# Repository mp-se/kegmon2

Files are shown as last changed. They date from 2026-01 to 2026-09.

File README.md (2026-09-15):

 









# KegMon - Monitoring the volume in your kegs

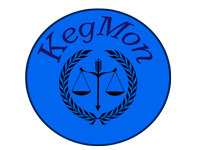
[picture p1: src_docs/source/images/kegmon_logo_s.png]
KegMon Logo


This is a project that I have done for my own Keezer, if you like it please feel free to suggest improvements. 

For docs see: https://mp-se.github.io/kegmon2/index.html

# License

This project is licensed under a **Dual License** model:

- **Open Source Use**: [GNU GPL v3](LICENSE)
- **Commercial Use**: [Commercial License Agreement](LICENSE_COMMERCIAL). Required for companies, businesses, or individuals distributing > 100 units/year.

See [LICENSE](LICENSE) for full details and the "Hobbyist Safe Harbor" clause.

# Hardware

* Supports Lolin ESP32 S3 PRO with Lolin TFT 320x200
* Loadcells and HX711 ADC converters
* DS18B20

# Features

* Can measure weight from 1 up to 4 scales
* **Advanced pour detection:** Dual-stage detection with slope validation and realistic flow rate bounds (-0.15 to -0.008 kg/sec)
* **Smart state machine:** 9-state system with intelligent weight stabilization and keg lifecycle tracking
* Real-time event system (pour detection, keg replacement, stabilization)
* Comprehensive statistics tracking (pour volume, frequency, state durations)
* Stable scale presentation (13 different filter algorithms including Kalman, EMA, Median)
* Support temperature/humidity sensor in one scale base
* Integration with Brewfather to retrive data on brew
* Integration with Brewspy to retrive data on brew and also update the remaning volume and pours
* Integration with Home Assistant
* InfluxDB export with event logging
* Weights and Volumes in Metric, Imperial (both US and UK)
* Pour detection for pours over 100 ml with configurable slope thresholds
* Estimation on how many glasses remain in the kegs
* Firmware update via UI
* One build for all hardware options
* Modern HTML5 UI
* Easy scale calibration
* 3D models and PCB

# Known Issues

When flashing the ESP32 s3 PRO the SD card mounting will likley fail, just turn power off/on and it will work again.

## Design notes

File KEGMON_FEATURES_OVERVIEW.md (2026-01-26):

# Kegmon - Features & System Overview

**Version:** January 2026  
**Status:** ✅ Production Ready

---

## Core Features

### 1. Multi-Scale Keg Monitoring

Monitor up to **4 independent kegs** simultaneously with individual tracking:

- **Per-scale monitoring:** Each scale has independent weight tracking and filtering
- **Real-time weight display:** Current keg weight on TFT screen or web interface
- **Load cell support:** HX711 amplifiers (one per scale) convert analog signals to digital readings
- **Independent configuration:** Each scale can be calibrated and configured separately
- **Isolation:** Problems with one scale don't affect others

**Use Cases:**
- Multiple taps in home brewery
- Different beer styles on different scales
- Mixed sizes (5L kegs, 10L kegs, 20L kegs)
- Simultaneous monitoring of different beverage types

---

### 2. Intelligent Pour Detection System

**Two-Stage Detection Strategy with Smart Slope Validation:**

#### Stage 1: Slope-Based Detection (Active) with Flow Rate Bounds
- **Real-time slope monitoring:** Analyzes weight change rate while in Stable state
- **Threshold-based trigger:** Detects pours exceeding -0.002 kg/sec
- **Physical validation:** Rejects slopes outside realistic beer tap flow rates
  - **Min realistic slope:** -0.15 kg/sec (maximum flow ~900 mL/min - very aggressive)
  - **Max realistic slope:** -0.008 kg/sec (minimum flow ~48 mL/min - very slow trickle)
  - **Result:** Anomalies like sensor errors or noise are automatically rejected
- **Responsive:** Identifies pour start within 1-2 seconds
- **Bar-environment optimized:** Tuned for typical bar pouring speeds (50-200 mL/sec, -0.01 to -0.02 kg/sec)

**How It Works:**
```
Stable state → Monitor slope of weight trend
↓
Slope < -0.002 kg/sec AND within -0.15 to -0.008 kg/sec range
↓
POURING event fired
↓
Wait for pour to complete (weight stabilizes)
↓
POUR_COMPLETED event with volume calculated
```

**Why Slope Bounds Matter:**
- Prevents false positives from sudden sensor anomalies
- Rejects unrealistic flow rates that indicate hardware errors
- Typical beer pours fall within -0.008 to -0.03 kg/sec
- Provides robustness without sacrificing sensitivity

**Result:** Precise slope-based detection ensures responsive pour tracking without false positives

---

### 3. State Machine with 9 States and Smart Stabilization

Each scale independently transitions through states based on weight patterns:

```
                 ┌─────────────────────┐
                 │       Idle          │
                 │  (No baseline set)  │
                 └──────────┬──────────┘
                            │
                            ▼
                 ┌──────────────────────┐
                 │   Stabilizing        │
                 │  (3 sec timeout)     │
                 │  (awaiting stable)   │
                 └──────────┬───────────┘
                            │
                            ▼
         ┌──────────────────────────────┐
         │        Stable                │
         │ (Baseline locked, monitoring)│
         │ (weight +/- 5% = stable)     │
         └─┬────────┬────────────────┬──┘
           │        │                │
           │        ▼                ▼ Keg removed
           │  ┌──────────────┐  ┌────────────────┐
           │  │ Pouring      │  │  KegAbsent     │
           │  │ (pour mode)  │  │  (30 sec wait) │
           │  └──────┬───────┘  └────────┬───────┘
           │         │                   │
           │         ▼                   ▼ New weight detected
           │  ┌──────────────────┐  ┌────────────────┐
           │  │ Restabilizing    │  │ ReplacingKeg   │
           │  │ (3 sec timeout)  │  │ (30 sec wait)  │
           │  │ (new baseline)   │  │ (new baseline) │
           │  └──────┬───────────┘  └────────┬───────┘
           │         │                       │
           └─────────┤───────────────────────┘
                     ▼
           ┌────────────────────┐
           │  Stable (new level)│
           └────────────────────┘
            ▲
            │ Weight increases >0.4kg
            │ (e.g., keg refill)
            │
            └─────────────────────┘
              (from Stable above)

Additional States:
- InvalidWeight: Sensor reading outside valid range (±50kg)
- CalibrationNeeded: Scale not yet calibrated
```

**Key Transitions with Smart Weight Management:**

- **Idle → Stabilizing:** Weight detected
- **Stabilizing → Stable:** 3-second timeout reached with variance < threshold
  - **Action:** Current weight locked as new baseline
  - **Confidence:** Grows as time in Stabilizing increases
- **Stable → Pouring:** Slope exceeds threshold AND within realistic flow bounds
  - **Action:** Enter pour detection mode
- **Stable → Restabilizing:** Weight increases by >0.4 kg (e.g., keg refill)
  - **Action:** Immediately capture new weight as target for re-stabilization
  - **Reason:** Significant increase indicates external change (refill), not sensor drift
  - **Fires:** Transitions to Restabilizing to confirm new level is stable
- **Pouring → Restabilizing:** Pour detection ends (weight stops dropping or timeout reached)
  - **Action:** Wait for Restabilizing state to confirm weight has truly stopped changing
  - **Reason:** Weight is still settling - Kalman filter hasn't fully caught up. Locking now would lock an intermediate value
- **Restabilizing → Stable:** Weight fully settled (zero slope) with significant drop detected
  - **Action:** NOW lock new baseline as `stableWeight` after confirming settlement
  - **Mechanism:** Slope-based detection triggers immediately when: weight dropped > 0.1kg AND slope ≈ 0
  - **Fallback:** Extended timeout (5x normal) forces transition if slope takes too long to stabilize
  - **Fires:** STABLE_LEVEL event with final baseline weight (not intermediate value)
- **Stable → KegAbsent:** Weight drops below 0.1 kg
  - **Action:** Start keg removal timeout
  - **Reason:** Confirms physical removal of keg
- **KegAbsent → ReplacingKeg:** New weight appears
  - **Action:** Start keg replacement timeout
  - **Reason:** New baseline needs stabilization time
- **ReplacingKeg → Stable:** 3-second timeout reached with variance < threshold
  - **Action:** New keg baseline locked, system ready to detect pours on new keg
  - **Fires:** STABLE_LEVEL event with new keg weight

**Settlement & Baseline Locking Algorithm (Improved Jan 2026):**
```
STABLE STATE: Weight has settled, baseline locked
  ↓ (Pour or weight change detected)
POURING STATE: Weight dropping, slope is negative
  ↓ (Pour completes - slope becomes positive or timeout)
RESTABILIZING STATE (CRITICAL IMPROVEMENT):
  │
  ├─ BASELINE NOT SET YET (deferred from Pouring state)
  │  System waits for weight to stabilize after pour ends
  │
  ├─ PATH A: Slope-Based Settlement Detection
  │  Continuously monitor slope of weight changes
  │  When slope ≈ 0 (settled):
  │    └──→ Immediately lock new baseline → transition to STABLE ✓
  │
  ├─ PATH B: Extended Timeout Fallback
  │  If slope takes too long (5x normal timeout):
  │    └──→ Force lock current weight as baseline → transition to STABLE ✓
  │
  └─ RESULT: Baseline locked only when weight is truly settled
             (not at intermediate values during Kalman filter lag)

STABLE STATE: New baseline confirmed, ready for next pour
```

**Key Improvement:**
Previously, baselines were locked in Pouring state at whatever the current weight was (often intermediate). Now, Restabilizing state waits for actual settlement before locking, ensuring accurate baselines on every pour.

---

### 4. Advanced Filtering System

**12 Filter Algorithms Available:**

| Filter | Type | Use Case |
|---|---|---|
| **Kalman** | Adaptive | Default - optimal for this application |
| EMA | Exponential Moving Average | Smooth trending |
| Median | Statistical | Outlier removal |
| Moving Average | Simple MA | Baseline filtering |
| Weighted MA | Weighted | Emphasis recent data |
| Butterworth | IIR | Smooth frequency response |
| Chebyshev | IIR | Steeper cutoff |
| Complementary | Hybrid | Combine sensor data |
| Alpha-Beta | Tracking | Predict weight trends |
| FIR | Finite Impulse | Linear phase response |
| Hampel | Robust | Outlier detection |
| Z-Score | Statistical | Anomaly detection |

**Current Configuration:**
- **Stability Detection:** Kalman filter (smooths weight for baseline)
- **Pour Detection:** Kalman filter (smooths weight for slope analysis)
- **Sampling Rate:** 10 SPS (10 readings per second from HX711)

**What Filters Do:**
1. Remove sensor noise and vibration
2. Smooth weight readings for accurate slope calculation
3. Improve baseline stability detection
4. Reduce false positive pour detection

---

### 4.1 Settlement Detection Implementation Details

**The Baseline Locking Problem (Solved Jan 2026):**

The weight detection system needs to identify when a pour has ended and lock a new baseline. The challenge: **when is the weight truly settled?**

**Previous Implementation (Incorrect):**
- Locked baseline immediately when Pouring state timeout occurred
- Result: Baselines set to **intermediate values** (e.g., 6.59kg instead of 6.10kg)
- Root cause: Kalman filter lag - weight continues changing for 10-40 seconds after pour ends
- Impact: First pour correct (large drop), subsequent pours degraded (stuck at intermediate values)

**Current Implementation (Correct):**

Two-stage approach ensures only **truly settled** weights are locked:

**Stage 1 - Pouring State Exits**
```cpp
When pour timeout reached:
  ├─ DEFER baseline update (don't set stableWeight here)
  └─ Transition to Restabilizing to await settlement
```

**Stage 2 - Restabilizing State (Settlement Detection)**
```cpp
While in Restabilizing:
  │
  ├─ PATH A: Slope-Based Detection (primary)
  │  └─ Calculate slope of current weight changes
  │  └─ When slope ≈ 0 (settled):
  │     └─ stableWeight = currentWeight (now truly settled)
  │     └─ Transition to Stable immediately
  │
  └─ PATH B: Extended Timeout (fallback)
     └─ If settlement detection slow (slope won't stabilize):
        └─ After 5x normal timeout (e.g., 6 seconds * 5 = 30 seconds):
           └─ stableWeight = currentWeight (force accept)
           └─ Transition to Stable (prevents deadlock)
```

**Example: Small Pour Sequence**
| Time | State | Weight | Slope | Action |
|---|---|---|---|---|
| 09:37:29 | Stable | 7.0127kg | ~0 | Original baseline locked |
| 09:37:32 | Pouring | 6.5910kg | -0.03 | Pour detected, tracking |
| 09:37:32 | Pouring | 6.3711kg | -0.02 | Still dropping |
| 09:37:46 | Restabilizing | 6.1695kg | -0.001 | Slope near zero! |
| 09:37:47 | Restabilizing | 6.1350kg | -0.0001 | Slope confirmed zero |
| 09:37:48 | **Stable** | **6.1024kg** | ~0 | **Final baseline locked ✓** |

**Why This Works:**
1. **Defers decision** - Doesn't assume weight is settled when timeout occurs
2. **Uses physics** - Detects actual settlement through slope analysis
3. **Self-correcting** - Updates baseline continuously as weight settles
4. **Robust** - Extended timeout prevents deadlock on unusual behavior
5. **Accurate** - Only accepts truly final values, not intermediate ones

---

### 5. Real-Time Event System

**Event Types Generated (10 Total):**

| Event | When Fired | Data Included |
|---|---|---|
| **SYSTEM_STARTUP** | Device boots | Timestamp |
| **STABLE_LEVEL** | Enters Stable state | Baseline weight |
| **POURING** | Pour begins | Start weight, timestamp |
| **POUR_COMPLETED** | Pour ends | Volume, duration, weight drop |
| **KEG_REMOVED** | Below 0.1 kg | Time in Stable state |
| **KEG_REPLACED** | New weight detected | New weight, replacement duration |
| **INVALID_WEIGHT** | Reading ±50kg | Reading value, variance |
| **LOAD_CELL_ERROR** | Signal lost | Error reason, signal quality |
| **LOAD_CELL_RECOVERED** | Signal restored | Signal quality, variance |
| **CALIBRATION_NEEDED** | Scale uncalibrated | Unit index |

**Event Queue:**
- 64-event circular buffer (thread-safe)
- Prevents loss of critical events
- Accessible via web API
- Exported to InfluxDB

---

### 6. Web API for Remote Monitoring

**RESTful API Endpoints:**

#### `/api/scale`
Returns current status of all 4 scales:
```json
{
  "scale": [
    {
      "index": 0,
      "connected": true,
      "state": "Stable",
      "confidence": 100,
      "stable_weight_kg": 24.5,
      "stable_volume_cl": 73.2,
      "sampling_rate": 10,
      "signal_quality": 95
    }
  ]
}
```

#### `/api/status`
Comprehensive device status with all scales and events

#### `/api/statistic`
Pour statistics, volume tracking, frequency analysis

#### `/api/hardware`
Hardware information, sensor status, GPIO configuration

#### `/api/config`
Read/write configuration settings (password protected)

**Features:**
- JSON responses for easy integration
- Per-scale filtering and state
- Volume in multiple units (kg, CL, oz)
- Real-time event history
- Confidence metrics

---

### 7. InfluxDB Integration

**Continuous Data Export:**

Every update pushes metrics to InfluxDB with:
- **Scale data:** Weight, volume, state (per scale)
- **Events:** Pour start/stop, keg changes, errors
- **Statistics:** Pour duration, volume, frequency
- **Quality:** Signal quality, filter variance, confidence
- **Hardware:** Temperature (if sensor present), sampling rate

**Data Points Captured:**
- 1,400,000+ data points per 24 hours (across all scales)
- Queryable per-scale data
- Event-based logging for pours
- Time-series trending
- Historical analysis

**Use Cases:**
- Track beer consumption over time
- Identify peak usage times
- Monitor scale health and signal quality
- Trend analysis (favorite beers, seasonal patterns)
- Integration with home automation

---

### 8. Multiple Unit Support

**Display Options:**

| Metric | Units Available |
|---|---|
| **Volume** | Centiliters (CL), US Fluid Ounces (oz), UK Fluid Ounces (fl oz) |
| **Weight** | Kilograms (kg), Pounds (lb) |
| **Temperature** | Celsius (°C), Fahrenheit (°F) |

**Configuration:**
- Per-device unit selection
- Automatic conversion in calculations
- Consistent formatting in web UI
- InfluxDB stores base units (liters, kg, Celsius)

---

### 9. Temperature & Humidity Monitoring

**Optional DS18B20 Sensor:**
- **Measurement:** Temperature inside keg or cooler
- **Range:** -10°C to +50°C (-14°F to +122°F)
- **Accuracy:** ±0.5°C
- **Integration:** One sensor per scale base possible

**Use Cases:**
- Monitor carbonation levels (temperature affects CO₂ solubility)
- Detect freezing conditions
- Track keg cooler performance
- Correlate temperature with consumption patterns

---

### 10. Integration with External Services

#### Home Assistant Integration
- Publish scale data via MQTT
- Expose states for automation
- Trigger notifications on pour events
- Create custom dashboards

#### Brewfather Integration
- Retrieve brew log data
- Link kegs to specific brews
- Automatic beer style metadata
- Track which beer is on which tap

#### Brewspy Integration
- Retrieve brew information
- Update keg volume status
- Sync pour counts
- Manage keg inventory

**Benefit:** Unified brewery management across systems

---

### 11. Local TFT Display Interface

**Lolin TFT 320×200 Screen:**

**Home Screen Shows:**
- Current weight for each scale
- Current volume for each scale
- Last pour volume
- Current state of each scale
- Temperature (if available)

**Interactive Controls:**
- Touch calibration
- Scale selection
- Configuration access
- Real-time updates

**Benefits:**
- Local status without internet
- Quick keg monitoring
- Calibration without web interface
- Emergency manual operations

---

### 12. Scale Calibration System

**Easy Calibration Process:**

1. **Place known weight on scale** (e.g., 1kg test weight)
2. **Input weight value** via web UI or TFT screen
3. **System calculates scale factor** (kg/ADC_count)
4. **Saves to flash memory**
5. **Automatic validation** (checks for NAN or invalid values)

**Features:**
- Per-scale independent calibration
- Persistent storage (survives reboots)
- Automatic detection of uncalibrated scales
- NAN safeguards prevent crashes
- Forced re-initialization after calibration

**Accuracy:** ±0.05 kg typical (load cell dependent)

---

### 13. Configuration Management

**Configurable Per-Scale:**

| Setting | Purpose |
|---|---|
| **Keg Type** | Volume capacity (5L, 10L, 20L, etc.) |
| **Keg Empty Weight** | Physical weight of empty keg |
| **Glass Volume** | Standard serving size |
| **Scale Factor** | Calibration value |
| **Filter Type** | Which algorithm to use |

**Configurable Globally:**

| Setting | Purpose | Default |
|---|---|---|
| **Stabilization Timeout** | How long until baseline locks | 3 seconds |
| **Pour Duration** | How long to wait after pour | 2 seconds |
| **Pour Slope Threshold** | Minimum slope to trigger pour | -0.002 kg/sec |
| **Min Pour Slope** | Slowest realistic pour speed | -0.15 kg/sec |
| **Max Pour Slope** | Fastest realistic pour speed | -0.008 kg/sec |
| **Volume Unit** | CL, oz, or fl oz | Centiliters |
| **Weight Unit** | kg or lb | Kilograms |
| **Temperature Unit** | C or F | Celsius |
| **InfluxDB URL** | Remote logging destination | — |
| **Home Assistant URL** | MQTT broker location | — |

**Slope Configuration Details:**
- **Slope Threshold (-0.002 kg/sec):** Initial detection threshold - triggers pour investigation
- **Min Pour Slope (-0.15 kg/sec):** Slowest acceptable pour = -0.15 kg/sec = 900 mL/min = extremely fast
- **Max Pour Slope (-0.008 kg/sec):** Fastest acceptable pour = -0.008 kg/sec = 48 mL/min = very slow pour
- **Validation Logic:** Pour only accepted if `slope < threshold` AND `min ≤ slope ≤ max`
- **Result:** Pours with realistic flow rates are detected; sensor anomalies or noise bursts are rejected
- **Tuning:** Adjust min/max bounds if your taps have unusual pouring characteristics

**Configuration Interface:**
- Web UI (HTML5 dashboard)
- TFT touch screen
- REST API for programmatic access
- Persistent flash storage

---

### 14. Multiple Pour Events Per Minute

**Rapid Pour Support:**

- Detects separate pours happening in quick succession
- 2-second timeout between pours before state resets
- Each pour generates separate event
- Accurate volume calculation per pour
- No loss of data even with overlapping pours

**Scenario:** Multiple people pouring at the same time → Separate events logged

---

### 15. Statistical Tracking

**Per-Scale Statistics:**

```
Total Pours: 247
Total Volume: 45.2 liters
Average Pour: 183 mL
Max Pour: 485 mL
Min Pour: 45 mL
Average Duration: 4.2 seconds
Most Pours In: Hour 18:00-19:00
Busiest Day: Friday
```

**Available In:**
- Web API (`/api/statistic`)
- InfluxDB time-series queries
- TFT screen summary view

---

### 16. Error Detection & Recovery

**Automatic Error Detection:**

| Error | Detection Method | Recovery |
|---|---|---|
| **Signal Timeout** | No data for 1+ second | Retry 3 times, then LOAD_CELL_ERROR |
| **Out of Range** | Reading ±50kg | InvalidWeight state |
| **NAN Value** | Invalid calculation | Ignore, use previous value |
| **Configuration Corruption** | NAN in scale factor | Default to 1.0 |
| **Signal Lost** | Consistent variance = 0 | LOAD_CELL_ERROR event |
| **Signal Recovered** | Variance normalizes | LOAD_CELL_RECOVERED event |

**Benefits:**
- Graceful degradation (fail safe)
- Automatic recovery when problem resolves
- No crashes from bad data
- Clear error events for troubleshooting

---

### 17. Firmware Over-the-Air Update

**Update Via Web Interface:**
- Upload new firmware binary
- Automatic rollback on failure
- Progress indicator
- No external tools required

**Benefits:**
- Deploy bug fixes remotely
- Add new features without manual update
- Easy recovery if update fails

---

### 18. Volume Calculation

**Multi-Step Volume Determination:**

1. **Weight Measurement:** Scale reads current weight
2. **Baseline Subtraction:** Removes empty keg weight
3. **Filter Application:** Smooths noise for accuracy
4. **Density Correction:** Accounts for beer density (~1.005 g/mL)
5. **Unit Conversion:** Converts to selected unit (CL, oz, etc.)

**Accuracy Factors:**
- Scale calibration quality
- Filter algorithm effectiveness
- Baseline measurement accuracy
- Temperature effects on beer density

**Typical Accuracy:** ±2% volume error (±20mL on 1-liter pour)

---

### 19. Last Pour Tracking

**Per-Scale Last Pour Record:**

- Volume of most recent pour
- Time of most recent pour
- Duration of that pour
- Weight before and after

**Displayed On:**
- TFT screen (main view)
- Web API response
- InfluxDB export

**Use Case:** Quick check of last serving without looking at full history

---

### 20. Confidence Metrics

**State-Dependent Confidence:**

| State | Confidence |
|---|---|
| Idle | 0% |
| Stabilizing | 0-100% (based on time elapsed) |
| Stable | 100% |
| Pouring | 0-100% (based on pour duration) |
| Restabilizing | 0-100% (based on time elapsed) |
| KegAbsent | 0-100% (based on time absent) |
| ReplacingKeg | 0-100% (based on replacement duration) |
| InvalidWeight | 0% |
| CalibrationNeeded | 0% |

**Purpose:** Indicates reliability of current measurement
- 0% = No reliable baseline yet
- 100% = Solid, confirmed measurement

---

## System Architecture

### Core Components

**HX711 Interface**
- Reads load cell analog signals at 10 SPS
- Converts to 24-bit digital values
- Applies scale factor for kg measurement
- Detects timeout and errors

**Filter System**
- 12 algorithm options
- Selected for both stabilization and pour detection
- Smooths input for accurate slope analysis
- Reduces false positives

**State Machine**
- 9 independent states per scale
- Timeout-driven transitions
- Event generation on state changes
- Per-scale isolation

**Event Queue**
- Thread-safe 64-event buffer
- Preserves event order
- Non-blocking on full (oldest event overwritten)
- Accessible via web API

**Web Server**
- RESTful API on port 80
- JSON responses
- Password-protected configuration
- Real-time updates

**InfluxDB Client**
- Asynchronous data export
- Buffered for reliability
- Configurable bucket and org
- Retry on network failure

---

## Performance Characteristics

| Metric | Value | Notes |
|---|---|---|
| **Sampling Rate** | 10 SPS | Per HX711 module |
| **State Transition Time** | <100 ms | Detection to event |
| **Pour Detection Latency** | 1-2 sec | Depends on slope |
| **Filter Lag** | <500 ms | Kalman settling time |
| **Event Queue Size** | 64 events | ~10 seconds at 6 Hz |
| **Memory Usage** | ~2 MB | Out of 8 MB total |
| **Update Frequency** | 10 Hz | Per-scale updates |
| **Web API Response** | <200 ms | Local network |

---

## Hardware Requirements

**Mandatory:**
- ESP32-S3 Pro microcontroller
- HX711 load cell amplifier (per scale)
- Load cells (50kg, 100kg, or custom)
- USB-C power supply

**Optional:**
- Lolin TFT 320×200 display
- DS18B20 temperature sensors (per scale)
- SD card for additional logging
- Ethernet/WiFi connectivity

**Power Consumption:**
- Idle: ~500 mW (with display)
- Active: ~1 W (with WiFi)
- Sleep: ~100 mW (radio off)

---

## Use Cases

### Home Brewery Monitoring
- Track consumption across multiple taps
- Monitor keg freshness
- Identify popular beers
- Plan keg rotation

### Bar/Brewery Production
- Pour accuracy tracking
- Shift-by-shift metrics
- Service speed optimization
- Inventory management

### Homebrew Club
- Shared keg monitoring
- Multi-brewery integration
- Event attendance tracking
- Consumption analytics

### Research/Testing
- Load cell calibration verification
- Filter algorithm comparison
- Signal quality analysis
- Hardware diagnostics

---

## Advantages Over Manual Tracking

| Feature | Manual | Kegmon |
|---|---|---|
| **Real-time volume** | No | Yes |
| **Automated logging** | No | Yes |
| **Historic trending** | No | Yes |
| **Error detection** | Manual | Automatic |
| **Integration** | Spreadsheet | InfluxDB, HA, Brewfather |
| **Accuracy** | ±10% | ±2% |
| **Time required** | 5+ min/pour | Automatic |
| **Data insights** | Manual analysis | Dashboard queries |

---

## Summary

Kegmon is a sophisticated keg monitoring system with advanced level detection that combines:

✅ **Real-time measurement** - Instant weight and volume  
✅ **Intelligent detection** - Dual-layer pour identification with slope validation  
✅ **Smart settlement detection** - Waits for weights to fully settle before locking baselines (Jan 2026 improvement)  
✅ **Event tracking** - Complete history of all changes  
✅ **Integration** - External service connectivity  
✅ **Automation** - Hands-off operation  
✅ **Accuracy** - ±2% volume measurement  
✅ **Reliability** - Redundancy and error recovery  
✅ **Scalability** - 4 independent scales  
✅ **Extensibility** - Custom filters, integrations  
✅ **User-friendly** - Web UI, TFT display, API  

**Latest Improvements (January 2026):**
- **Settlement Detection Algorithm:** Baselines now locked only after weight is confirmed settled (not at intermediate values)
- **Slope-Based Accuracy:** Uses real-time slope analysis to detect when Kalman filter has caught up
- **Extended Timeout Fallback:** 5x timeout ensures system never deadlocks on edge cases
- **Multi-Pour Robustness:** First pour accuracy maintained while subsequent pours now lock correct baselines

Perfect for home brewers, brewpubs, and keg-centric establishments that want accurate, automated tracking of beverage consumption with reliable baseline detection across all pour events.

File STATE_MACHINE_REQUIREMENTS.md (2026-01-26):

# Kegmon State Machine Requirements

## Overview
Each scale has an independent state machine with 10 states. The machine tracks weight changes and detects pours, keg replacements, and weight anomalies.

**Critical Principle:** `stableWeight` is the baseline weight against which all changes are measured. It should only be SET when entering STABLE state, never during transitions.

**stableWeight Initialization:** `stableWeight = NaN` indicates the baseline has NOT been established yet. Only set to an actual weight value when transitioning TO STABLE state. Checking `isnan(stableWeight)` determines if baseline is valid.

**stableVolume:** Always calculated from `stableWeight` on-the-fly using the weight-to-volume converter. NOT stored independently. This is just an alternative representation (liters vs kilograms) of the same baseline value. Volume is calculated based on the beers FG which has a slight impact on the weight.

**currentWeight Source:** All conditions comparing `currentWeight` use the **Kalman filter output** (FILTER_KALMAN, index 12) as the source. The Kalman filter provides the most stable, noise-reduced weight estimate suitable for state machine decision-making. Other filters (EMA, Butterworth, Median) are available for display/logging but do NOT affect state transitions.

**Slope Detection Source:** Pour detection (slope calculation) uses the **fast-responding filter** (FILTER_EMA or FILTER_WMA) to detect rapid weight changes. The Kalman filter (stability filter) is used for establishing the baseline and validating the final settled weight, but is too slow for responsive pour triggering. Trigger pour if the fast filter detects a slope exceeding the threshold and within realistic flow rate bounds.

---

## Global Conditions (Checked Every Cycle - ALL States EXCEPT IDLE and DISABLED)

These conditions override state-specific logic and trigger transitions from ANY state **AFTER initialization**. Check in this priority order:

**IMPORTANT: Pre-emptive State Check**
If a scale is in the **DISABLED** state, all global conditions and state machine processing are skipped. The scale is considered non-functional for the duration of the session.

**IMPORTANT: Filter Warm-up Grace Period**
Global conditions DO NOT apply during IDLE state (first 2 seconds). This allows filters (Kalman, EMA) to initialize and converge without false error triggers from startup transients. Only basic weight validity checks apply in IDLE. Once the system transitions OUT of IDLE to SETTLING, all global conditions become active and remain active for all subsequent states.

### 1. **Signal Quality Critical** (Exit to LOAD_CELL_ERROR)
   - Condition: `signalQualityPercent < 20 OR consecutiveErrors >= 10`
   - Action: Transition to LOAD_CELL_ERROR
   - Fire: LOAD_CELL_ERROR event with error reason details
   - **Priority: HIGHEST** - sensor health check comes before all else
   
   **Signal Quality Calculation:**
   ```
   signalQualityPercent = 100 - (consecutiveErrors * 5)
   Minimum: 0%, Maximum: 100%
   ```
   
   **Entry Triggers (detailed):**
   - **TIMEOUT**: HX711 not responding for X ms → enter immediately (Severity: Critical)
   - **NAN_VALUE**: Reading is NaN (invalid float) → enter immediately (Severity: Critical)
   - **STUCK_VALUE**: Same value repeated (variance = 0 for 20+ reads) → enter after 5+ consecutive (Severity: Critical)
   - **CALIBRATION_INVALID**: ScaleFactor = 0 or invalid offset → enter immediately (Severity: Critical)
   - **PHANTOM_SPIKE**: Single-read weight change > maxSingleReadChangeKg (e.g., > 0.5kg) → counts as error, contributes to quality score (Severity: High)
   - **Quality Threshold**: `signalQualityPercent < 20` (≥4 consecutive errors, 95% recent reads bad) → enter when crossed
   - **Error Accumulation**: `consecutiveErrors >= 10` (10+ bad reads in a row) → enter when crossed
   
   **Recovery Conditions (Exit from LOAD_CELL_ERROR):**
   - Both conditions must be met:
     1. `signalQualityPercent > 80` (fewer than 4 errors in recent reads)
     2. `consecutiveErrors == 0` (confirmed clean reads)
   - Action: Transition back to previous state OR to SETTLING if previous state unknown
   - Fire: LOAD_CELL_RECOVERED event
   - Recovery Timeout: If stuck > 5 minutes with no improvement, alert user: "Scale sensor unresponsive - manual intervention may be needed"

### 2. **Scale Becomes Uncalibrated** (Exit to CALIBRATION_NEEDED)
   - Condition: `scaleFactor == 0.0 OR scaleFactor becomes invalid`
   - Action: Transition to CALIBRATION_NEEDED
   - Fire: CALIBRATION_NEEDED event
   - **Priority: HIGH** - cannot process readings without calibration
   - **Except**: If already in LOAD_CELL_ERROR (stay there)

### 3. **Weight Invalid** (Exit to INVALID_WEIGHT)
   - Condition: `currentWeight < -0.1kg OR currentWeight > (kegWeight + beerCapacity * 1.1)`
   - Action: Transition to INVALID_WEIGHT
   - Fire: INVALID_WEIGHT event
   - **Priority: HIGH** - sensor reading out of bounds
   - **Except**: If already in INVALID_WEIGHT (stay there) or LOAD_CELL_ERROR (stay there)

### 4. **Weight Absent** (Exit to KEG_ABSENT)
   - Condition: `-0.1kg <= currentWeight < (kegWeight * 0.9)` (weight below minimum valid keg weight)
   - Action: Transition to KEG_ABSENT
   - Fire: KEG_REMOVED event (if coming from a state that should report removal)
   - **Priority: HIGH** - no valid weight to process
   - **Except**: If already in KEG_ABSENT (stay there)

**Weight Range Summary (NO OVERLAP):**
- **INVALID_WEIGHT**: `currentWeight < -0.1kg` OR `currentWeight > (kegWeight + beerCapacity * 1.1)` (out of bounds)
- **KEG_ABSENT**: `-0.1kg <= currentWeight < (kegWeight * 0.9)` (weight present but keg too light)
- **VALID FOR PROCESSING**: `(kegWeight * 0.9) <= currentWeight <= (kegWeight + beerCapacity * 1.1)` (keg present with reasonable load)

**Note:** State-specific exit conditions only apply after global conditions are checked and false.

---

## Anomalous Data Detection

**Phantom/Spike Detection (Global, all states except IDLE):**

Between consecutive reads, weight changes are expected to be gradual during normal operation (settling, pouring, or equilibrium). Sudden large changes between individual reads indicate sensor artifacts or noise spikes and should be treated as signal quality issues.

**Detection Logic:**
- Monitor `|currentWeight(t) - currentWeight(t-1)|` between consecutive sensor reads
- Threshold: If single-cycle change > `maxSingleReadChangeKg` (e.g., 0.5kg in 100ms), it's physically unrealistic for a keg and indicates phantom data
- Action: Count as signal error without triggering LOAD_CELL_ERROR immediately
- Recovery: If the next read is normal, the spike is isolated; if multiple spikes occur, quality score drops

**Impact on Signal Quality:**
- Each phantom spike increments `consecutiveErrors` (same as other error types)
- Contributes to `signalQualityPercent = 100 - (consecutiveErrors * 5)` calculation
- If spikes accumulate: quality < 20% OR consecutiveErrors >= 10 → LOAD_CELL_ERROR

**Rationale:**
- Filters (Kalman, EMA) help smooth phantom data, but don't catch all spikes before they affect slope calculations
- Detection at read-level provides early warning of sensor degradation
- Distinguishes between normal variance (expected) and anomalous jumps (artifact)
- Prevents false pour detection from phantom drops in STABLE state

---

## Validation Criteria Principle

**ALL state transition conditions require explicit validation thresholds** to prevent false triggers from transient sensor noise and single-sample anomalies. Each condition must specify either:

1. **Reading Count Validation:** Minimum number of consecutive readings meeting the condition
2. **Time-Based Validation:** Minimum elapsed time the condition must be true
3. **Combination:** Both reading count AND time duration required

**Why This Matters:**
- Single-sample changes (1 reading showing an anomaly) should NOT trigger state transitions
- Transient sensor noise, EMI spikes, and filter initialization artifacts can produce 1-2 odd readings
- Multiple consecutive readings confirm a real state change vs. noise
- Typical sensor reads at ~10Hz, so 3 readings ≈ 300ms confirmation window

**Validation Summary Table (by state transition):**
| Transition | Condition | Validation | Threshold |
|---|---|---|---|
| STABLE → POURING | Negative slope detected | Reading count | ≥3 readings (Fast Filter) |
| STABLE → SETTLING | Weight change (inc/dec) | Reading count | ≥3 readings (±0.4kg/±0.1kg) |
| POURING → STABLE (normal) | Slope positive | Reading count | ≥1 reading confirms |
| POURING → SETTLING (weight removal) | Steep drop rate | Reading count | ≥3 consecutive readings (slope < -0.15 kg/s) |
| POURING → STABLE (timeout) | Time elapsed | Time-based | ≥2 seconds |
| SETTLING → STABLE | Weight settled | Time-based + slope | ≥6 seconds WITH slope < threshold |
| IDLE → SETTLING | Weight present + filters ready | Time-based | ≥2 seconds |
| KEG_ABSENT → KEG_REPLACED | Weight reappears | Reading count | ≥1 reading (immediate detection) |
| KEG_ABSENT → timeout event | Time in absence | Time-based | ≥30 seconds (periodic: 30, 60, 90...) |

---

## State Definitions & Data Management

### 1. IDLE State
**Purpose:** Initialization - no baseline established yet. Filters are initializing and converging.

**Filter Warm-up Grace Period:** During IDLE state, global error conditions (Signal Quality, Calibration, Weight Invalid) are NOT enforced. This allows the system to initialize without false errors from startup transients. Only weight presence/absence is checked for transition eligibility.

**Data State:**
- `stableWeight = NaN` (not set - use `isnan(stableWeight)` to check)
- `state = Idle`
- All slope tracking reset
- Filters initializing (Kalman, EMA, etc. beginning to converge)

**Minimum Duration:** Must remain in IDLE for at least 2 seconds after valid weight detected to allow filters to initialize and converge. This prevents using noisy or stale readings as the baseline.

**Exit Conditions:** (Global conditions NOT checked - see above)

1. **Weight Present & Filters Initialized** (Exit to SETTLING)
   - Conditions (ALL must be true):
     - `currentWeight >= (kegWeight * 0.9)` (weight at least 90% of empty keg)
     - `currentWeight <= (kegWeight + beerCapacity * 1.1)` (weight not exceeding max)
     - `timeInState >= 2000ms` (filters have had time to initialize)
   - Action: Transition to SETTLING
   - Fire: SETTLING_STARTED event
   - Why: Weight is valid and filters are initialized, safe to establish baseline
   - **NOTE:** After this transition, all global conditions become active for all remaining states
   - **EXPLICIT:** Global Condition #4 (Weight Absent: currentWeight < kegWeight * 0.9) is NOT checked in IDLE, but exit condition requires weight >= (kegWeight * 0.9) to proceed
   - **State Transition:** IDLE → SETTLING (not STABILIZING - SETTLING is the single unified state for both initial and re-stabilization)

---

### 2. SETTLING State
**Purpose:** Wait for weight to settle into a stable baseline. Handles initial stabilization (from IDLE) and re-stabilization after pours/changes (from POURING or STABLE).

**Data State:**
- `stableWeight` NOT YET SET (or preserved from before)
- Moving average of weight readings
- Tracking time in state
- Variance calculation for stability detection
- Slope tracking to detect settlement

**Settlement Detection Logic (unified):**
A weight is "stabilized" when the Kalman filter slope remains within acceptable range for a sustained period:

- **Slope Within Acceptable Range:** `avgSlope > minPourSlope/100` (extremely small: > -0.0015 kg/s or near-zero)
  - **CRITICAL:** Slope is calculated from the **Kalman/stability filter**, not the fast EMA filter
  - This ensures we're checking when the actual baseline has stabilized, not just the fast-responding filter
  - This is 10x stricter than before (old: 0.015 kg/s, new: -0.0015 kg/s)
  - Filters must show nearly zero rate of change before declaring stability

- **AND** sustained stability: `timeWithinSlopeThreshold >= 6000ms` (slope stays in range for continuous 6 seconds)
  - Unlike a fixed timer that waits 6 seconds then checks slope once, this requires **sustained convergence**
  - If slope exceeds threshold at ANY point, the timer resets to 0
  - Only when slope remains within acceptable range for 6 **consecutive** seconds does stabilization trigger
  - This prevents locking while filter is still drifting or oscillating
  - Ensures filter has truly reached equilibrium, not just temporarily within threshold
  - More adaptive than fixed time: fast-settling weights stabilize quickly, slow-settling weights take longer

- **OR** extended timeout reached (6 sec × 5 = 30 sec fallback) with weight within stability window
  - Prevents indefinite settling if filter cannot converge
  - Triggers after 30 seconds regardless of slope behavior

**Exit Conditions:** (Global conditions checked first - see above)

1. **Weight Stabilized** (Exit to STABLE)
   - Condition: Weight stabilization detected (see logic above - ALL conditions must be met)
   - Action: Set `stableWeight = currentWeight`, Transition to STABLE
   - Fire: STABLE_LEVEL event with newly settled weight
   - Why: Settlement confirmed with stricter criteria (filters truly at rest), new baseline locked in
 
---

### 3. STABLE State
**Purpose:** Baseline locked, monitoring for pours or weight changes

**Data State:**
- `stableWeight` = locked baseline (DO NOT MODIFY)
- Continuously calculating slope of weight changes

**Exit Conditions:**

1. **Pour Detected** (weight dropping with sustained negative slope)
   - Condition: `avgSlope < pourSlopeThreshold` AND within realistic range (-0.15 to -0.008)
   - Validation: Requires ≥3 consecutive readings in the fast filter showing negative slope before triggering
   - Action: Transition to POURING
   - Fire: POURING event
   - Rationale: 3-reading requirement prevents false detection from transient 1-2 sample weight fluctuations. Realistic range ensures we only trigger on actual pours, not slow drift or sudden removal.

2. **Weight Increase > 0.4kg** (Weight addition)
   - Condition: `currentWeight >= stableWeight + 0.4kg`
   - Validation: Requires 0.4kg increase sustained for at least 3 consecutive readings (≥ 300ms at typical 10Hz rate)
   - Action: Transition to SETTLING
   - Fire: WEIGHT_CHANGE_DETECTED event
   - Rationale: DO NOT modify stableWeight - SETTLING will determine true baseline. Multiple readings confirm real weight addition, not sensor spike.

3. **Weight Decrease > 0.1kg** (Passive/Slow Pour Detection)
   - Condition: `currentWeight <= stableWeight - 0.1kg`
   - Validation: Requires 0.1kg decrease sustained for at least 3 consecutive readings.
   - Action: Transition to SETTLING
   - Fire: WEIGHT_CHANGE_DETECTED event
   - Rationale: Catches slow pours or weight drops that were too slow for the slope trigger. SETTLING will eventually return to STABLE.

---

### 4. POURING State
**Purpose:** Detect and measure active pour event

**Data State:**
- `prePourWeight = stableWeight` (weight before pour started)
- `stableWeight` NOT MODIFIED during pour
- Slope tracking continuing
- `pourVolume` accumulating

**Exit Conditions:**

1. **Pour Completes** (weight stabilized at new level with minimum hold time)
   - Condition: ALL of the following must be true:
     - `timeInState >= 1000ms` (minimum 1 second to allow weight to physically settle)
     - `kalmanSlope > pourSlopeThreshold` (Kalman filter confirms slope positive/near-zero - stable baseline, not noisy fast filter)
     - `(prePourWeight - currentWeight) >= levelDecreaseThreshold` (minimum 0.1 kg weight drop confirmed)
   - Validation: 
     - **Filter Source:** Use **Kalman filter slope**, not EMA or WMA. The Kalman filter provides the stable, noise-reduced baseline confirmation that weight has truly settled to its final level
     - **Time Gate:** `timeInState >= 1000ms` ensures scale has had time to physically dampen oscillations and stabilize around the new equilibrium weight
     - **Slope Confirmation:** Slope must be positive/near-zero (not just for 1 sample, but consistently) to confirm weight is no longer dropping
     - **Weight Drop Validation:** Confirms actual pour occurred (>= 0.1 kg minimum)
   - Action: Set `stableWeight = currentWeight`, Transition to STABLE
   - Fire: POUR_COMPLETED event (if weight drop >= threshold) OR STABLE_LEVEL event (if weight drop < threshold)
   - Why: 
     - **Time buffer prevents premature exit:** Hardware load cells exhibit mechanical settling time (~0.5-1.5 seconds). Exiting before this completes captures intermediate weight as final, not the true settled weight
     - **Kalman filter ensures true stabilization:** The Kalman filter (stable baseline) shows the actual equilibrium. Fast filters (EMA, WMA) can show false stability while still trending. Entry uses WMA for fast detection (catch pours quickly), but exit must use Kalman for confirmation (ensure weight truly settled)
     - **Prevents false pours:** Without time gate and Kalman validation, pour completes while scale still oscillating toward final weight
     - **Real-world example:** 1.014 kg drop over 4 minutes (slow pour) needs 1+ second post-pour for load cell to stop moving and settle to its new equilibrium (~6.7374 kg). Exiting at 1.4 seconds before settlement complete captured intermediate weight instead of final level

2. **Unrealistic Drop Rate** (slope too steep)
   - Condition: `avgSlope < minPourSlope` (e.g., < -0.15 kg/s)
   - Validation: Requires ≥3 consecutive readings with slope < minPourSlope before confirming weight removal (prevents single-read transient spikes)
   - Action: Transition to SETTLING
   - Fire: SETTLING_STARTED event
   - Why: Sudden drop indicates weight removal, not a pour. Pours are gradual. Multiple confirmations prevent false detection. Transition to SETTLING to re-verify stability.

3. **Pour Timeout**
   - Condition: `timeInState >= pourDurationMs` (2 seconds elapsed)
   - Validation: Time-based - absolute 2-second threshold (no reading count needed, time is the gate)
   - Action: Set `stableWeight = currentWeight`, Transition to STABLE
   - Fire: POUR_COMPLETED event
   - Why: Timeout ensures baseline locked for next pour, regardless of slope. Prevents indefinite POURING state

---

### 5. KEG_ABSENT State
**Purpose:** Waiting for keg to be replaced (30 second timeout)

**Data State:**
- `stableWeight` unchanged from when keg was removed
- Waiting for weight to reappear

**Exit Conditions:** (Global conditions checked first - see above)

1. **Weight Reappears** (weight >= min keg weight)
   - Condition: `currentWeight >= (kegWeight * 0.9)` (weight at least 90% of empty keg)
   - Action: Set `stableWeight = currentWeight`, Transition to REPLACING_KEG
   - Fire: KEG_REPLACED event
   - Why: New keg detected
   - Priority: Checked BEFORE timeout event; if weight recovers, exit KEG_ABSENT immediately

2. **Timeout Expired** (stays in KEG_ABSENT, awaiting keg)
   - Condition: `timeInState >= 30 seconds` (allow extended wait for replacement)
   - Action: Stay in KEG_ABSENT (do not exit state, but log timeout)
   - Fire: KEG_ABSENT_TIMEOUT event (reminder that keg has been missing for 30+ seconds)
   - Firing Pattern: Event fires once when timeInState crosses 30 seconds, then again at 60 seconds, 90 seconds, etc. (every 30-second boundary)
   - Why: Keg missing for extended period - user notification/reminder; periodic events for extended monitoring

---

### 6. REPLACING_KEG State
**Purpose:** Wait for new keg weight to stabilize (3 second timeout)

**Data State:**
- `stableWeight = currentWeight` (new keg baseline being established)
- Updated with each reading

**Exit Conditions:** (Global conditions checked first - see above)

1. **Timeout reached with stable readings** (Exit to STABLE)
   - Conditions (ALL must be true):
     - `timeInState >= 3000ms` (3 second minimum duration)
     - `weightVariance < stabilityThreshold` (readings are stable/converged)
   - Action: Transition to STABLE
   - Fire: STABLE_LEVEL event with newly settled weight
   - Why: New keg baseline confirmed and stable

2. **Weight drops** (keg removed again) (Exit to KEG_ABSENT)
   - Condition: `currentWeight < 0.1kg` (covered by global weight absent condition)
   - Action: Transition to KEG_ABSENT
   - Fire: KEG_REMOVED event
   - Why: Keg removal detected during new keg stabilization

---

### 7. INVALID_WEIGHT State
**Purpose:** Sensor is reporting invalid readings (out of valid weight range)

**Data State:**
- `stableWeight` unchanged
- No weight processing

**Exit Conditions:** (Global conditions checked first - see above)

1. **Weight Returns to Valid Range** (Exit to SETTLING)
   - Condition: `currentWeight >= (kegWeight * 0.9) AND currentWeight <= (kegWeight + beerCapacity * 1.1)`
   - Action: Transition to SETTLING
   - Fire: SENSOR_RECOVERED event (sensor reading returned to valid range)
   - Why: Sensor recovered, need to re-establish baseline

---

### 8. LOAD_CELL_ERROR State
**Purpose:** ADC/Load cell signal is lost, unresponsive, or too unreliable (sensor is dead)

**Data State:**
- `stableWeight` unchanged but not used
- `signalQualityPercent` < 20 (very poor signal)
- `consecutiveErrors` high (multiple bad reads)
- Scale should be treated as offline/unusable

**Entry:** Triggered by Global Condition #1 (Signal Quality Critical). See Global Conditions section for detailed entry triggers.

**Exit Condition (Recovery):**
   - Conditions (ALL must be true):
     - `signalQualityPercent > 80` (signal quality recovered)
     - `consecutiveErrors == 0` (confirmed clean reads)
   - Action: Transition back to previous state OR to SETTLING if previous state unknown
   - Fire: LOAD_CELL_RECOVERED event
   - Why: Sensor has recovered, can resume monitoring

---

### 10. DISABLED State
**Purpose:** Scale unit is permanently inactive because ADC hardware (HX711) was not detected at startup.

**Data State:**
- `stableWeight = NaN`
- No weight processing, no GPIO polling, no background loop execution.
- This state is terminal for the current session (hardware is only scanned at boot).

**Differentiator:**
- **DISABLED**: Hardware chip (ADC) is physically missing or failed core initialization. Permanent for session.
- **LOAD_CELL_ERROR**: Hardware chip is present, but the 4-wire load cell signal is lost, noisy, or disconnected. Recoverable if signal returns.

**Exit Condition:**
- None (requires system reboot to re-scan hardware).

---

## Error Reason Details

| Reason | Cause | Recoverable | Action |
|---|---|---|---|
| **TIMEOUT** | HX711 SPI timeout, clock issues, wiring loose | Yes | Resume on next successful read |
| **NAN_VALUE** | ADC returned invalid float, memory corruption | Maybe | Check wiring, restart sensor |
| **OUT_OF_RANGE** | Reading > ±50kg (physical sensor limit) | Yes | This is INVALID_WEIGHT, not LoadCellError |
| **STUCK_VALUE** | Sensor frozen at one value, mechanical jam | No | Requires physical intervention |
| **PHANTOM_SPIKE** | Unexplained large jump between reads (> 0.5kg), EMI artifact, loose connection | Yes | Check wiring, shield from EMI, restart |
| **EXCESSIVE_NOISE** | Electromagnetic interference, bad power supply | Yes | Shield wiring, check PSU |
| **CALIBRATION_INVALID** | ScaleFactor = 0 or offset not set | No | Requires recalibration |

**Note on AvgSlope Logging:** When firing pour-related events (POURING, POUR_COMPLETED), the `AvgSlope` CSV field should use the **Kalman filter slope** for consistency. The Kalman filter provides the stable, noise-reduced slope suitable for historical analysis. EMA slope is used internally for fast detection but not logged.

---

## Key Principles

### 1. **stableWeight Management**
- **Initialization:** `stableWeight = NaN` (indicates "not set")
- **Set:** Only when transitioning TO STABLE state
- **Check:** Use `isnan(stableWeight)` to verify if baseline is valid
- **Preserve:** Never modified during transitions
- **Reference:** Used to detect significant changes (pours, additions)

### 2. **Slope Tracking and Filter Selection**
- **Reset:** On transitions from STABLE (to POURING or SETTLING)
- **Purpose:** Detect whether weight is changing or settled
- **Filter Selection (CRITICAL):**
  - **Entry to POURING (Pour Detection):** Use **WMA (Weighted Moving Average)** or fast-response filter for slope detection. Fast filters catch rapid weight changes quickly. Entry should trigger as soon as slope exceeds threshold to detect pours responsively.
  - **Exit from POURING (Pour Completion):** Use **Kalman filter** for slope validation. Kalman provides the stable, noise-reduced baseline. Exit requires confirmation that weight has truly settled to its equilibrium, not just a transient dip from noise or fast-filter overshoot.
  - **SETTLING state:** Use **Kalman filter** for slope checks to confirm stable baseline before locking into STABLE state
  - **Rationale:** Entry and exit use different filters because they serve different purposes:
    - Entry: Detect changes fast (WMA responsive, low latency)
    - Exit: Confirm true stability (Kalman stable baseline, filtered noise)
- **Threshold Rationale:** Slope threshold `avgSlope > -minPourSlope/100` (~0.0015 kg/s) is necessary because:
  - Raw readings can fluctuate ±0.001-0.002 kg due to sensor noise
  - Kalman filter can show micro-movements as it reaches steady state
  - Previous threshold (0.015 kg/s) allowed declarations of stability while filter still settling
  - Stricter threshold ensures filters have truly reached equilibrium before locking baseline
  - Empirical InfluxDB data shows filters converge within ~6 seconds at this threshold

### 4. **stableVolume Calculation**
- **Calculation:** `stableVolume = weightToVolume(stableWeight)`
- **Storage:** NOT stored independently - always calculated on-the-fly
- **Timing:** Only valid when `stableWeight` is valid (not NaN)
- **Purpose:** Alternative representation of baseline for display/reporting

### 5. **Global Conditions** (see above section)
- **Signal Quality Critical:** Always checked first across all states
- **Calibration:** Always checked for scale validity
- **Weight Invalid:** Always checked for sensor range validity
- **Weight Absent:** Always checked to detect missing kegs
- **Priority:** Global conditions override state-specific logic
- **Reference:** See "Global Conditions" section for exact thresholds and priority order

### 6. **Event Firing - Always on State Transitions**
**CRITICAL:** Every state transition MUST fire an event. This maintains a clear, unambiguous state history for logging, UI updates, and external integrations. No silent transitions.

**State Entry Events:**
- SETTLING_STARTED: Fired when entering SETTLING state (initial baseline or re-stabilization)
- STABLE_LEVEL: Fired when entering STABLE state
- POURING: Fired when entering POURING state
- KEG_REMOVED: Fired when entering KEG_ABSENT
- KEG_REPLACED: Fired when entering REPLACING_KEG
- INVALID_WEIGHT: Fired when entering INVALID_WEIGHT state
- LOAD_CELL_ERROR: Fired when entering LOAD_CELL_ERROR state
- CALIBRATION_NEEDED: Fired when entering CALIBRATION_NEEDED state
- LOAD_CELL_RECOVERED: Fired when exiting LOAD_CELL_ERROR state (recovery)
- SENSOR_RECOVERED: Fired when exiting INVALID_WEIGHT state
- POUR_COMPLETED: Fired when exiting POURING state

**State-Specific Events:**
- WEIGHT_CHANGE_DETECTED: Fired when large weight increase (>0.4kg) detected in STABLE (awaiting settlement confirmation)
- KEG_ABSENT_TIMEOUT: Fired when KEG_ABSENT state exceeds 30 seconds (reminder for user)

---

## Event Specifications

All events follow the CSV logging format defined in [EVENT_LOGGING_FORMAT.md](EVENT_LOGGING_FORMAT.md). This section specifies which parameters should be populated for each event type.

### 1. SYSTEM_STARTUP
**When**: System initialization or reboot. Use this to identify session boundaries.

**CSV Parameters**:
- **Timestamp**: Event time
- **Scale**: Scale/unit number (1-4)
- **EventType**: `SYSTEM_STARTUP`

**Example**:
```
1,2026-01-18 10:00:00,1,SYSTEM_STARTUP,0,0,0,0,0,0,0,0,0,0,,0,0,0
```

---

### 2. SETTLING_STARTED
**When**: Transition from IDLE → SETTLING (initial stabilization) OR from STABLE/POURING → SETTLING (re-stabilization)

**CSV Parameters**:
- **Timestamp**: Event time
- **Scale**: Scale/unit number (1-4)
- **EventType**: `SETTLING_STARTED`
- **DurationMs**: 0 (event just started)
- **CurrWeight**: Current weight when settling begins

**Example**:
```
1,2026-01-18 10:00:05,1,SETTLING_STARTED,0,0,0,0,0,0,0,0,0,23.5,,0,0,0
```

---

### 3. STABLE_LEVEL
**When**: Transition from SETTLING → STABLE (baseline confirmed and locked)

**CSV Parameters**:
- **Timestamp**: Event time
- **Scale**: Scale/unit number (1-4)
- **EventType**: `STABLE_LEVEL`
- **StableWeight**: New baseline weight (just locked)
- **StableVolume**: Calculated volume at this baseline
- **DurationMs**: Time spent in SETTLING state before stabilization
- **Variance**: Final variance at stabilization time

**Example**:
```
1,2026-01-18 10:00:10,1,STABLE_LEVEL,23.5,70.5,0,0,0,0,5000,0,0,0,,0,0.15,0
```

---

### 4. POURING
**When**: Transition from STABLE → POURING (slope exceeds threshold)

**CSV Parameters**:
- **Timestamp**: Event time
- **Scale**: Scale/unit number (1-4)
- **EventType**: `POURING`
- **PrePourWeight**: Weight before pour (stableWeight at moment of detection)
- **AvgSlope**: Initial slope/rate that triggered pour detection
- **CurrWeight**: Current weight when pour detected

**Example**:
```
1,2026-01-18 10:03:15,1,POURING,0,23.5,23.5,0,0,0,0,-0.245,0,0,,0,0,0
```

---

### 5. WEIGHT_CHANGE_DETECTED
**When**: Transition from STABLE → SETTLING (large weight increase > 0.4kg detected)

**CSV Parameters**:
- **Timestamp**: Event time
- **Scale**: Scale/unit number (1-4)
- **EventType**: `WEIGHT_CHANGE_DETECTED`
- **PrevWeight**: Previous stable weight (baseline before increase)
- **CurrWeight**: Current weight that triggered detection
- **Variance**: Current variance (may be high during transient)

**Example**:
```
1,2026-01-18 10:15:20,1,WEIGHT_CHANGE_DETECTED,0,0,0,0,0,0,0,0,23.2,23.7,,0,0.45,0
```

---

### 6. POUR_COMPLETED
**When**: Transition from POURING → SETTLING (any exit condition: normal completion, timeout, or impossible rate)

**CSV Parameters**:
- **Timestamp**: Event time
- **Scale**: Scale/unit number (1-4)
- **EventType**: `POUR_COMPLETED`
- **PrePourWeight**: Weight at pour start (stableWeight before pour)
- **PostPourWeight**: Weight when pour ended (current weight)
- **PourWeight**: Weight difference (PrePourWeight - PostPourWeight)
- **PourVolume**: Volume equivalent of weight difference
- **DurationMs**: Time in POURING state
- **AvgSlope**: Average pour rate during pour

**Example**:
```
1,2026-01-18 10:03:25,1,POUR_COMPLETED,23.5,23.1,0.4,0.12,10000,-0.040,0,0,,0,0,0
```

---

### 7. KEG_REMOVED
**When**: Transition from STABLE/other → KEG_ABSENT (weight drops below kegWeight * 0.9)

**CSV Parameters**:
- **Timestamp**: Event time
- **Scale**: Scale/unit number (1-4)
- **EventType**: `KEG_REMOVED`
- **PrevWeight**: Weight before removal (last known keg weight)
- **CurrWeight**: Current weight (now below minimum)

**Example**:
```
1,2026-01-18 10:15:30,1,KEG_REMOVED,0,0,0,0,0,0,0,0,23.5,0.5,,0,0,0
```

---

### 8. KEG_REPLACED
**When**: Transition from KEG_ABSENT → REPLACING_KEG (weight reappears >= kegWeight * 0.9)

**CSV Parameters**:
- **Timestamp**: Event time
- **Scale**: Scale/unit number (1-4)
- **EventType**: `KEG_REPLACED`
- **PrevWeight**: Weight when absent (0 or last low reading)
- **CurrWeight**: New keg weight detected

**Example**:
```
1,2026-01-18 10:15:35,1,KEG_REPLACED,0,0,0,0,0,0,0,0,0.5,20.2,,0,0,0
```

---

### 9. KEG_ABSENT_TIMEOUT
**When**: Periodic event in KEG_ABSENT state every time timeInState >= 30 seconds

**CSV Parameters**:
- **Timestamp**: Event time (when timeout period exceeded)
- **Scale**: Scale/unit number (1-4)
- **EventType**: `KEG_ABSENT_TIMEOUT`
- **DurationMs**: Time keg has been absent (timeInState)
- **CurrWeight**: Current weight (should be below minimum)

**Note**: This event may fire multiple times if keg remains absent (every 30 second cycle)

**Example**:
```
1,2026-01-18 10:16:00,1,KEG_ABSENT_TIMEOUT,0,0,0,0,0,0,30000,0,0,0.3,,0,0,0
```

---

### 10. INVALID_WEIGHT
**When**: Transition to INVALID_WEIGHT state (weight outside valid range: < -0.1kg OR > kegWeight + beerCapacity * 1.1)

**CSV Parameters**:
- **Timestamp**: Event time
- **Scale**: Scale/unit number (1-4)
- **EventType**: `INVALID_WEIGHT`
- **CurrWeight**: Weight that triggered error (out of bounds)

**Example**:
```
1,2026-01-18 10:25:48,2,INVALID_WEIGHT,0,0,0,0,0,0,0,0,0,52.3,,0,0,0
```

---

### 11. LOAD_CELL_ERROR
**When**: Transition to LOAD_CELL_ERROR state (signal quality critical)

**CSV Parameters**:
- **Timestamp**: Event time
- **Scale**: Scale/unit number (1-4)
- **EventType**: `LOAD_CELL_ERROR`
- **SignalErrorReason**: Error type (TIMEOUT, NAN_VALUE, STUCK_VALUE, CALIBRATION_INVALID, or empty for quality threshold)
- **SignalQuality**: Current signal quality percentage (< 20 or > 80 at recovery)
- **Variance**: Current variance reading
- **ConsecutiveErrors**: Count of consecutive errors

**Example**:
```
1,2026-01-18 10:22:15,2,LOAD_CELL_ERROR,0,0,0,0,0,0,0,0,0,0,TIMEOUT,15,0.85,6
```

---

### 12. LOAD_CELL_RECOVERED
**When**: Transition from LOAD_CELL_ERROR → previous state (signal quality recovered)

**CSV Parameters**:
- **Timestamp**: Event time
- **Scale**: Scale/unit number (1-4)
- **EventType**: `LOAD_CELL_RECOVERED`
- **SignalQuality**: Recovered signal quality percentage (> 80)
- **Variance**: Variance at recovery
- **ConsecutiveErrors**: Should be 0 at recovery

**Example**:
```
1,2026-01-18 10:22:25,2,LOAD_CELL_RECOVERED,0,0,0,0,0,0,0,0,0,0,,92,0.12,0
```

---

### 13. SENSOR_RECOVERED
**When**: Transition from INVALID_WEIGHT → SETTLING (weight returns to valid range)

**CSV Parameters**:
- **Timestamp**: Event time
- **Scale**: Scale/unit number (1-4)
- **EventType**: `SENSOR_RECOVERED`
- **CurrWeight**: Weight that returned to valid range

**Example**:
```
1,2026-01-18 10:26:05,2,SENSOR_RECOVERED,0,0,0,0,0,0,0,0,0,21.5,,0,0,0
```

---

### 14. CALIBRATION_NEEDED
**When**: Transition to CALIBRATION_NEEDED state (scale not calibrated: scaleFactor == 0.0)

**CSV Parameters**:
- **Timestamp**: Event time
- **Scale**: Scale/unit number (1-4)
- **EventType**: `CALIBRATION_NEEDED`

**Example**:
```
1,2026-01-18 10:26:00,3,CALIBRATION_NEEDED,0,0,0,0,0,0,0,0,0,0,,0,0,0
```

---

### 15. CALIBRATION_COMPLETE
**When**: Transition from CALIBRATION_NEEDED → IDLE (calibration set successfully)

**CSV Parameters**:
- **Timestamp**: Event time
- **Scale**: Scale/unit number (1-4)
- **EventType**: `CALIBRATION_COMPLETE`

**Example**:
```
1,2026-01-18 10:26:10,3,CALIBRATION_COMPLETE,0,0,0,0,0,0,0,0,0,0,,0,0,0
```

---

### 16. DISABLED
**When**: Transition to DISABLED state at startup when ADC hardware is not found.

**CSV Parameters**:
- **Timestamp**: Event time
- **Scale**: Scale/unit number (1-4)
- **EventType**: `DISABLED`

**Example**:
```
1,2026-01-18 10:00:01,4,DISABLED,0,0,0,0,0,0,0,0,0,0,,0,0,0
```

---

## Scenario Examples

### Scenario A: Normal Pour
```
STABLE (weight=7.0kg, stableWeight=7.0kg)
  → slope becomes negative
  → POURING (weight=6.5kg, stableWeight=7.0kg[unchanged])
  → slope becomes positive
  → STABLE (weight=6.4kg, stableWeight=6.4kg[NOW set])
```

### Scenario B: Weight Spike (Transient)
```
STABLE (weight=7.0kg, stableWeight=7.0kg)
  → weight spikes to 7.5kg (> 0.4kg increase)
  → SETTLING (weight=7.5kg, stableWeight=7.0kg[unchanged])
  → weight settles back at 7.0kg
  → STABLE (weight=7.0kg, stableWeight=7.0kg[confirmed])
```

### Scenario C: Keg Replacement
```
STABLE (weight=7.0kg, stableWeight=7.0kg)
  → weight drops to 0kg
  → KEG_ABSENT (weight=0kg, stableWeight=7.0kg)
  → new weight appears at 8.0kg
  → REPLACING_KEG (weight=8.0kg, stableWeight=8.0kg)
  → settles at 8.0kg
  → STABLE (weight=8.0kg, stableWeight=8.0kg[set])
```

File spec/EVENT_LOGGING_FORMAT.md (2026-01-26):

# Event Logging Format

## Overview

Kegmon logs all system events to CSV files on the SD card for persistent event history, analysis, and debugging. Each event is logged as a single CSV row with a version number for schema compatibility and extensibility.

## File Organization

### Log Files

- **Current log**: `/data.csv`
- **Rotation files**: `/data1.csv`, `/data2.csv`, `/data3.csv`
- **File size limit**: 16 KB (configurable via `MAX_LOG_FILE_SIZE`)
- **Max rotated files**: 4 files total (configurable via `MAX_LOG_FILES`)

### File Rotation Behavior

When `/data.csv` exceeds 16 KB:
1. `/data3.csv` is deleted (oldest)
2. `/data2.csv` → `/data3.csv`
3. `/data1.csv` → `/data2.csv`
4. `/data.csv` → `/data1.csv`
5. New empty `/data.csv` is created

This ensures you always have the 4 most recent log files with recent events accessible in `/data.csv`.

## CSV Format

### Structure: Version Per Row

Each row contains a version number as the first column for schema evolution:

```
Version,Timestamp,Scale,EventType,StableWeight,StableVolume,PrePourWeight,PostPourWeight,PourWeight,PourVolume,DurationMs,AvgSlope,PrevWeight,CurrWeight,SignalErrorReason,SignalQuality,Variance,ConsecutiveErrors
```

### Column Definitions

| # | Column | Type | Description | Units |
|---|---|---|---|---|
| 1 | **Version** | int | Schema version for parser evolution | - |
| 2 | **Timestamp** | string | ISO 8601 datetime (RTC-based) | YYYY-MM-DD HH:MM:SS |
| 3 | **Scale** | int | Scale/unit number (1-4 for U1-U4) | - |
| 4 | **EventType** | string | Event type name | - |
| 5 | **StableWeight** | float | Baseline weight when stable detected | kg |
| 6 | **StableVolume** | float | Calculated volume at stable baseline | L |
| 7 | **PrePourWeight** | float | Weight before pour started | kg |
| 8 | **PostPourWeight** | float | Weight after pour completed | kg |
| 9 | **PourWeight** | float | Weight change during pour | kg |
| 10 | **PourVolume** | float | Volume change during pour | L |
| 11 | **DurationMs** | uint64 | Event duration (stabilization or pour) | milliseconds |
| 12 | **AvgSlope** | float | Average pour rate | kg/sec |
| 13 | **PrevWeight** | float | Previous weight (for KEG_REMOVED) | kg |
| 14 | **CurrWeight** | float | Current weight (for KEG_REPLACED) | kg |
| 15 | **SignalErrorReason** | string | Error type (for LOAD_CELL_ERROR/RECOVERED) | - |
| 16 | **SignalQuality** | uint8 | Signal quality percentage | 0-100 |
| 17 | **Variance** | float | Reading variance | kg² |
| 18 | **ConsecutiveErrors** | uint16 | Error count | - |

### Empty Fields

Columns that don't apply to an event are left empty (consecutive commas), maintaining uniform row structure for easy CSV parsing.

## Event Types

All 16 event types log with identical column structure. Relevance varies by type:

### 1. SYSTEM_STARTUP

Marks system initialization/restart. Use this to identify session boundaries.

**Relevant Columns**: Timestamp, Scale, EventType only

**Example**:
```
1,2026-01-18 10:00:00,1,SYSTEM_STARTUP,0,0,0,0,0,0,0,0,0,0,,0,0,0
```

### 2. SETTLING_STARTED

Weight settling begins (initial stabilization from IDLE or re-stabilization after pour/change).

**Relevant Columns**: Timestamp, Scale, EventType, CurrWeight, DurationMs (0)

**Example**:
```
1,2026-01-18 10:00:05,1,SETTLING_STARTED,0,0,0,0,0,0,0,0,0,23.5,,0,0,0
```

### 3. STABLE_LEVEL

Keg baseline locked, ready for pouring. Fired after a weight change once the sensor signal has remained stable (slope < ±0.0015 kg/s) for at least 6 consecutive seconds.

**Relevant Columns**: Timestamp, Scale, EventType, StableWeight, StableVolume, DurationMs (will be >= 6000ms)

**Example**:
```
1,2026-01-18 10:00:10,1,STABLE_LEVEL,24.5,73.5,0,0,0,0,6000,0,0,0,,0,0,0
```

### 4. POURING

Pour detected, slope calculation and real-time volume tracking begin.

**Relevant Columns**: Timestamp, Scale, EventType, PrePourWeight, AvgSlope (instantaneous)

**Example**:
```
1,2026-01-18 10:03:15,1,POURING,24.5,0,24.5,0,0,0,0,-0.245,0,0,,0,0,0
```

### 5. WEIGHT_CHANGE_DETECTED

Large weight increase detected in STABLE state (> 0.4kg), awaiting settlement confirmation.

**Relevant Columns**: Timestamp, Scale, EventType, PrevWeight, CurrWeight, Variance

**Example**:
```
1,2026-01-18 10:15:20,1,WEIGHT_CHANGE_DETECTED,0,0,0,0,0,0,0,0,23.2,23.7,,0,0.45,0
```

### 6. POUR_COMPLETED

Pour finished with complete metrics.

**Relevant Columns**: Timestamp, Scale, EventType, PrePourWeight, PostPourWeight, PourWeight, PourVolume, DurationMs, AvgSlope

**Example**:
```
1,2026-01-18 10:03:25,1,POUR_COMPLETED,24.5,23.8,0.7,0.21,10000,0.0070,0,0,,0,0,0
```

### 7. KEG_REMOVED

Weight dropped below minimum threshold.

**Relevant Columns**: Timestamp, Scale, EventType, PrevWeight, CurrWeight

**Example**:
```
1,2026-01-18 10:15:30,1,KEG_REMOVED,0,0,0,0,0,0,0,0,23.2,0.1,,0,0,0
```

### 8. KEG_REPLACED

New keg detected, weight increased above minimum.

**Relevant Columns**: Timestamp, Scale, EventType, PrevWeight, CurrWeight

**Example**:
```
1,2026-01-18 10:15:35,1,KEG_REPLACED,0,0,0,0,0,0,0,0,0.1,19.8,,0,0,0
```

### 9. KEG_ABSENT_TIMEOUT

Periodic reminder that keg has been absent for 30+ seconds (fires in KEG_ABSENT state every 30-second cycle).

**Relevant Columns**: Timestamp, Scale, EventType, DurationMs, CurrWeight

**Example**:
```
1,2026-01-18 10:16:00,1,KEG_ABSENT_TIMEOUT,0,0,0,0,0,0,30000,0,0,0.3,,0,0,0
```

### 10. INVALID_WEIGHT

Sensor reading outside valid range (±50kg for HX711).

**Relevant Columns**: Timestamp, Scale, EventType only

**Example**:
```
1,2026-01-18 10:25:48,2,INVALID_WEIGHT,0,0,0,0,0,0,0,0,0,0,,0,0,0
```

### 11. LOAD_CELL_ERROR

Signal lost or became unreliable (timeout, NAN, stuck value, noise, etc.).

**Relevant Columns**: Timestamp, Scale, EventType, SignalErrorReason, SignalQuality, Variance, ConsecutiveErrors

**Example**:
```
1,2026-01-18 10:22:15,2,LOAD_CELL_ERROR,0,0,0,0,0,0,0,0,0,0,TIMEOUT,25,0.85,3
```

### 12. LOAD_CELL_RECOVERED

Signal restored to normal operation (signal quality > 80% and clean reads).

**Relevant Columns**: Timestamp, Scale, EventType, SignalQuality, Variance

**Example**:
```
1,2026-01-18 10:22:20,2,LOAD_CELL_RECOVERED,0,0,0,0,0,0,0,0,0,0,,95,0.02,0
```

### 13. SENSOR_RECOVERED

Weight returned to valid range after being in INVALID_WEIGHT state.

**Relevant Columns**: Timestamp, Scale, EventType, CurrWeight

**Example**:
```
1,2026-01-18 10:26:05,2,SENSOR_RECOVERED,0,0,0,0,0,0,0,0,0,21.5,,0,0,0
```

### 14. CALIBRATION_NEEDED

Scale calibration missing (scale factor == 0.0f).

**Relevant Columns**: Timestamp, Scale, EventType only

**Example**:
```
1,2026-01-18 10:26:00,3,CALIBRATION_NEEDED,0,0,0,0,0,0,0,0,0,0,,0,0,0
```

### 15. CALIBRATION_COMPLETE

Calibration successfully completed. System ready for weight monitoring.

**Relevant Columns**: Timestamp, Scale, EventType only

**Example**:
```
1,2026-01-18 10:26:10,3,CALIBRATION_COMPLETE,0,0,0,0,0,0,0,0,0,0,,0,0,0
```

### 16. DISABLED

Scale unit disabled at startup because ADC hardware (HX711) was not found. This is a permanent state for the session.

**Relevant Columns**: Timestamp, Scale, EventType only

**Example**:
```
1,2026-01-18 10:00:01,4,DISABLED,0,0,0,0,0,0,0,0,0,0,,0,0,0
```

## Signal Error Reasons

Used in LOAD_CELL_ERROR events:

| Reason | Description |
|---|---|
| TIMEOUT | HX711 read timeout, no data from sensor |
| NAN_VALUE | Sensor returned NaN (not a number) |
| OUT_OF_RANGE | Reading exceeds ±50kg sensor limits |
| STUCK_VALUE | Same value repeated, zero variance |
| PHANTOM_SPIKE | Unexplained large jump between reads (> 0.5kg), EMI artifact |
| EXCESSIVE_NOISE | Jitter beyond acceptable threshold |
| CALIBRATION_INVALID | Scale factor or offset not properly set |

## Timestamps

- **Format**: ISO 8601 datetime (`YYYY-MM-DD HH:MM:SS`)
- **Source**: RTC (Real-Time Clock via NTP WiFi sync)
- **Baseline**: System startup time (captured in first event)
- **Accuracy**: ±1 second (resolution is per-second in CSV, millisecond tracking in device)

## Version Strategy

The schema version number enables backward-compatible changes:

- **v1**: Current format (18 columns)
- **v2+**: Future enhancements can add columns without breaking parsers reading v1 data

## Example Analysis

### Session Example

```
1,2026-01-18 10:00:00,1,SYSTEM_STARTUP,0,0,0,0,0,0,0,0,0,0,,0,0,0
1,2026-01-18 10:00:06,1,STABLE_LEVEL,24.5,73.5,0,0,0,0,6000,0,0,0,,0,0,0
1,2026-01-18 10:03:15,1,POURING,24.5,0,24.5,0,0,0,0,0.0245,0,0,,0,0,0
1,2026-01-18 10:03:25,1,POUR_COMPLETED,24.5,23.8,0.7,0.21,10000,0.0070,0,0,,0,0,0
1,2026-01-18 10:03:32,1,STABLE_LEVEL,23.8,71.4,0,0,0,0,6000,0,0,0,,0,0,0
```

Reading this:
- System started at 10:00:00
- Scale 1 baseline locked at 24.5 kg (73.5 L) after 6 seconds of sustained stability
- Pour detected at 10:03:15
- Pour complete at 10:03:25: 0.7 kg poured (0.21 L) over 10 seconds at 0.007 kg/sec
- New baseline at 23.8 kg (71.4 L) after 6 seconds of sustained stabilization

## Configuration

Edit constants in [event_logger.hpp](src/event_logger.hpp):

```cpp
#define LOG_VERSION 1              // Current schema version
#define MAX_LOG_FILE_SIZE (16 * 1024)  // 16 KB per file
#define MAX_LOG_FILES 4            // 4 files total (data.csv + 3 rotations)
#define LOG_BASE_FILENAME "/data"  // CSV file base name
#define LOG_FILE_EXTENSION ".csv"  // File extension
```

## Usage

The logger is initialized and called automatically:
- **Initialization**: `setup()` → `myEventLogger.init()`
- **Logging**: Main loop event processing → `myEventLogger.logEvent(event)`
- **File rotation**: Automatic when size threshold exceeded

No manual configuration needed unless adjusting constants.

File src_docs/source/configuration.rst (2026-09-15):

.. _configuration:

Configuration
-------------

This guide explains how to configure KegMon through its web interface. Access the device via a web browser using its IP address or mDNS name (e.g., kegmon.local). The interface is divided into sections for device settings, taps, integrations, and tools.

Index
*****

The main dashboard displays general device information, including temperatures and status. Only available data is shown.

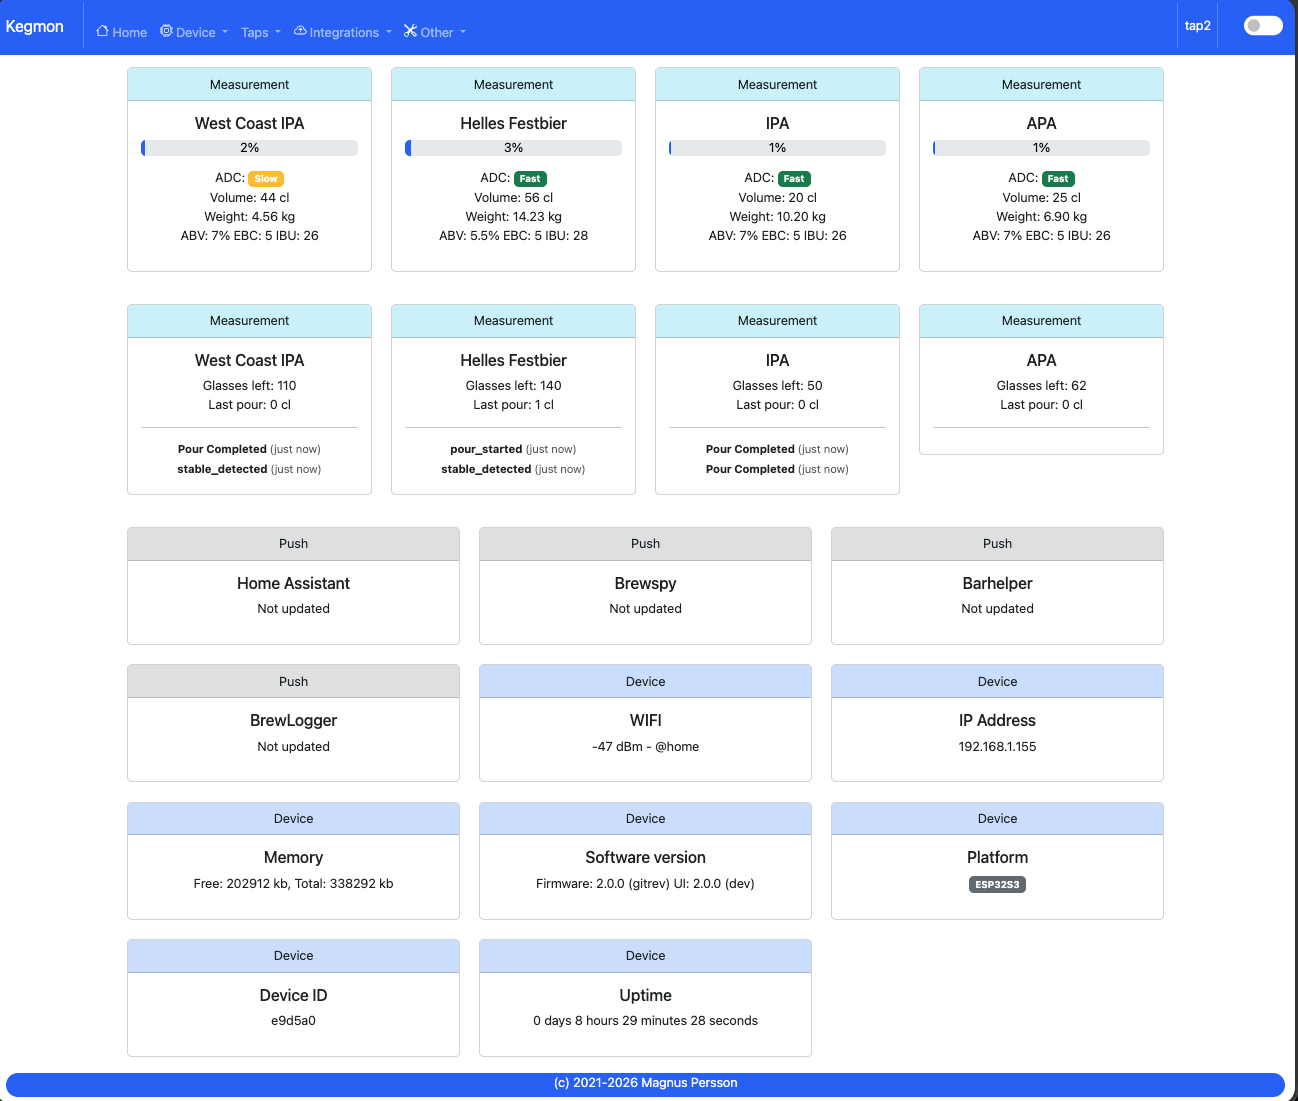
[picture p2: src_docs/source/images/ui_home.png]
Index page


Device - Settings
*****************

Configure general device preferences here.

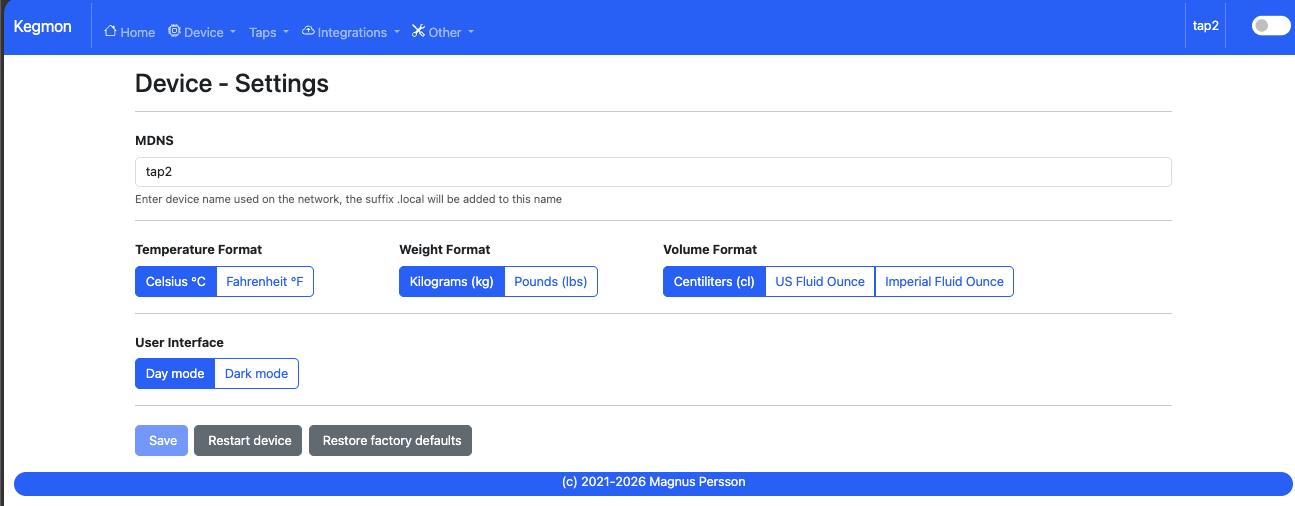
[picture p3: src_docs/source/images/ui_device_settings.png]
Device Settings


* **MDNS**: Set a custom name for the device on the network (requires mDNS support).
* **Temperature format**: Choose Celsius or Fahrenheit for temperature display.
* **Weight unit**: Select kg or lbs for weight measurements.
* **Volume unit**: Choose cl, UK fl. oz, or US fl. oz for volume display.
* **Dark Mode**: Toggle between light and dark UI themes (also available via the menu bar).

Device - Calibration
********************

Calibrate your scales in three easy steps for accurate weight measurements.

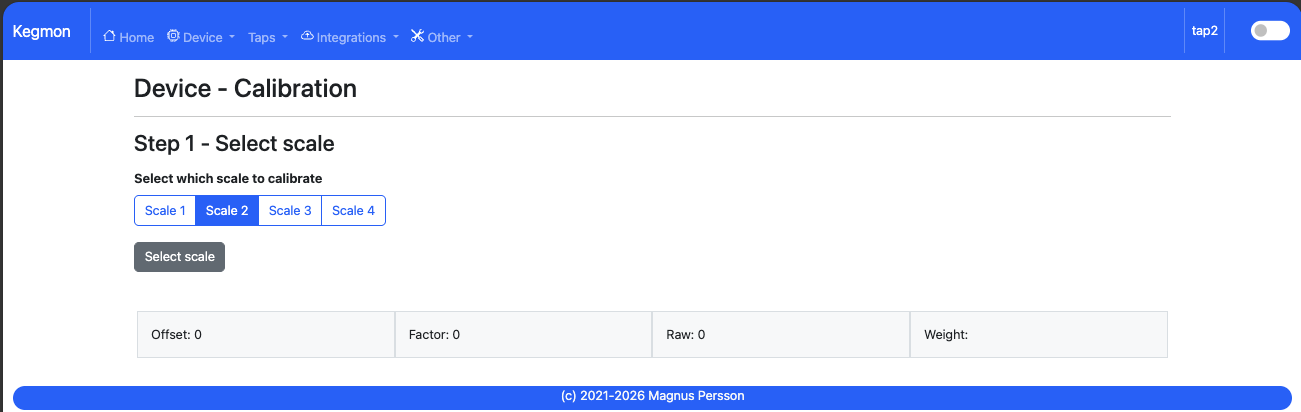
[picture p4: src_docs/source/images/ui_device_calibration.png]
Device calibration


* **STEP 1 - Tare scale**: Select the scale from the dropdown and ensure it's empty, then tare to zero.
* **STEP 2 - Calculate factor**: Place an object of known weight on the scale and enter its weight. The software calculates the calibration factor.
* **STEP 3 - Validate**: Place another object of known weight and verify the reading. If accurate, calibration is complete.

Device - Stability
******************

Monitor the stability of your hardware setup to ensure reliable readings.

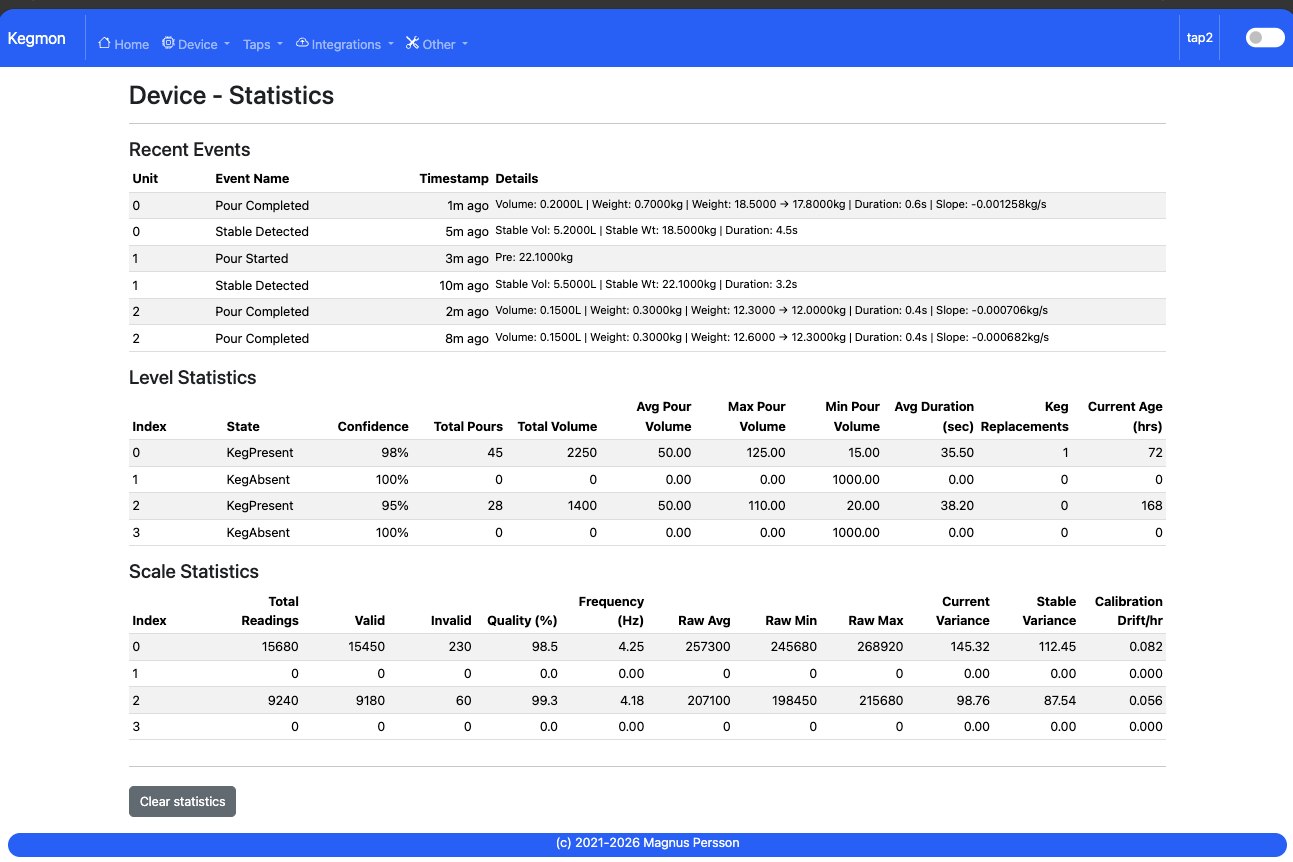
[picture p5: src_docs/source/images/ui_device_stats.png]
Statistics


This page helps diagnose unstable builds. Keep the browser open to view historical data (raw, Kalman-filtered, and stable values) for analysis. Data is stored in the browser and resets on refresh.

Device - Events
***************

The Events page displays persistent event history when an SD card is mounted.
Refresh the data and optionally filter it by scale. The current session's most
recent events are also shown in the statistics view.

Device - WiFi
*************

Manage WiFi connections and settings.

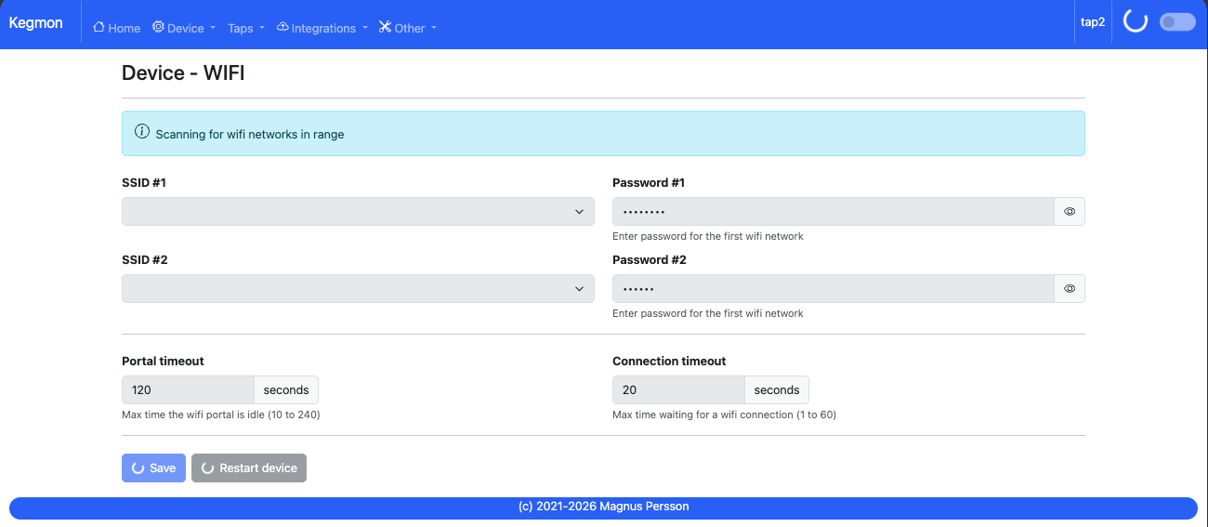
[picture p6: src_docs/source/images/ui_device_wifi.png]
Device WiFi


* **SSID #1/Password #1**: Primary network credentials.
* **SSID #2/Password #2**: Secondary network for fallback (optional).
* **Portal timeout**: Time (in seconds) the WiFi portal remains active when triggered (e.g., by tapping reset 2-3 times within 3 seconds).
* **Connect timeout**: Maximum time allowed for WiFi connection attempts.

Taps - Settings
***************

Configure individual tap settings for volume calculations and beer details.

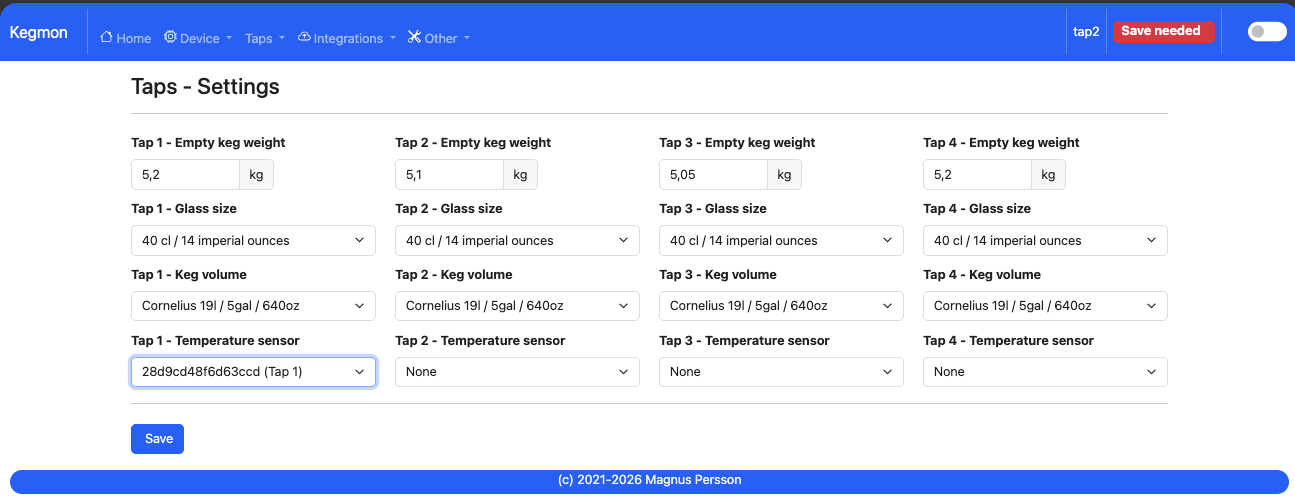
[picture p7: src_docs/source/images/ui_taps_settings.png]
Tap settings


* **Empty keg weight**: Weight of the empty keg, used to calculate remaining beer volume.
* **Glass volume**: Standard glass size for estimating remaining pours.
* **Keg volume**: Standard keg size for validating weight and calculating remaining volume.
* **Temperature sensor**: Assign a detected DS18B20 sensor ID to the tap. The
  sensors share a OneWire bus; an unassigned tap falls back to the first sensor
  value when one is available.

Taps - Beers
************

View and manage beers on tap, with options to import from integrations.

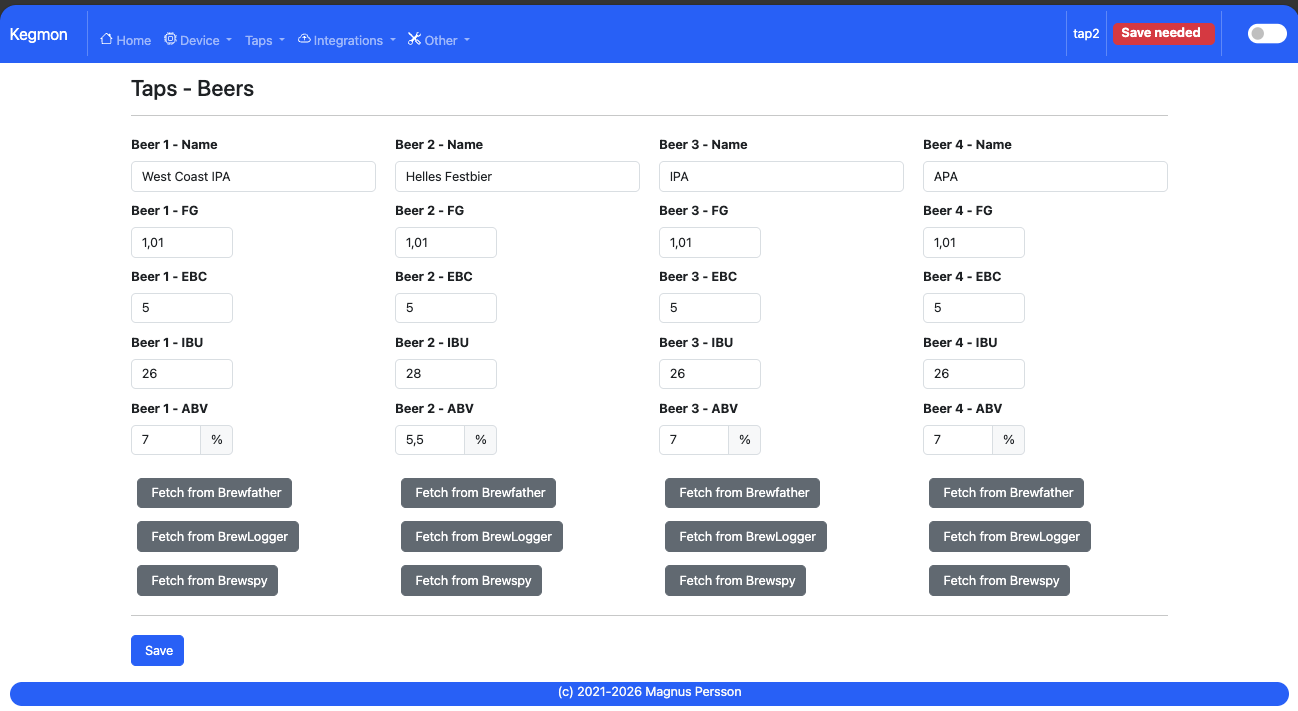
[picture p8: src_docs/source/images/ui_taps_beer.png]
Tap beers


Use buttons to import data from BrewSpy or Brewfather. Beer name, FG, EBC, ABV and IBU are imported if available

Taps - History
**************

Review recent pour history for each tap.

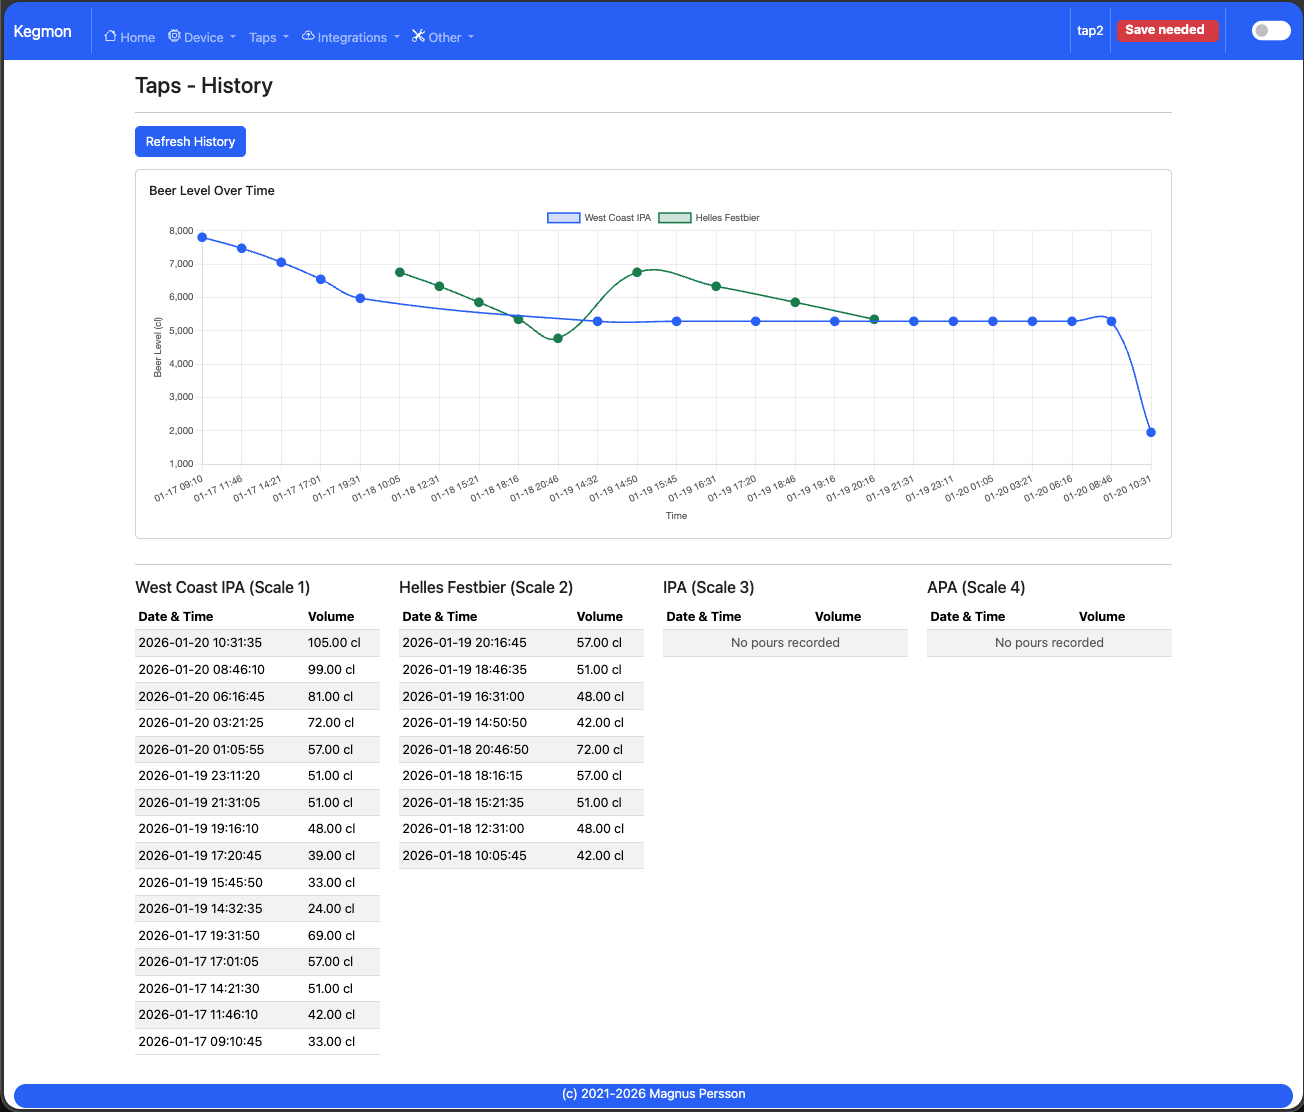
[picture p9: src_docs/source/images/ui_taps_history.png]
Tap history


Displays the latest pours for beers on tap.

Integration - Home Assistant
****************************

Set up MQTT for Home Assistant integration.

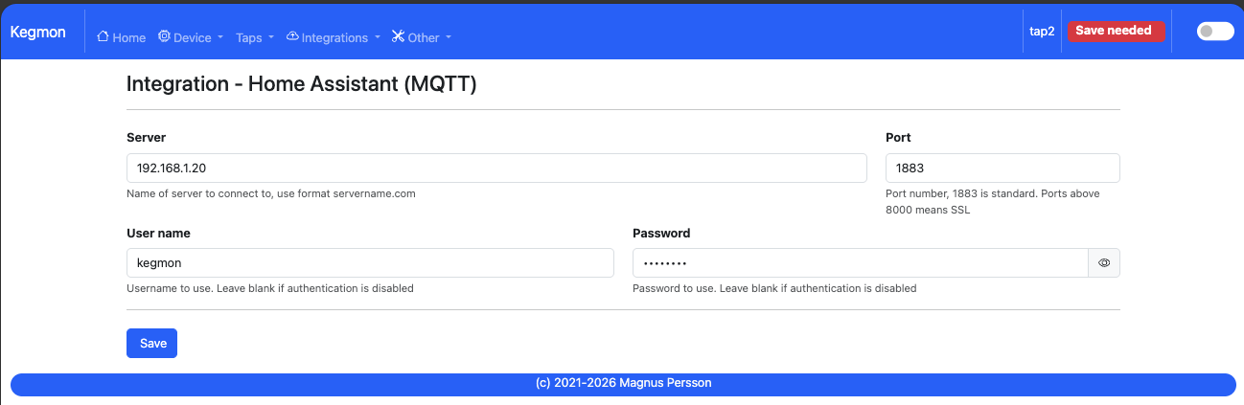
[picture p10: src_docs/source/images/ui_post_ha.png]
Home Assistant integration


Configure MQTT server details for data export to Home Assistant.

Integration - Brewfather
************************

Connect to Brewfather for brew data import.

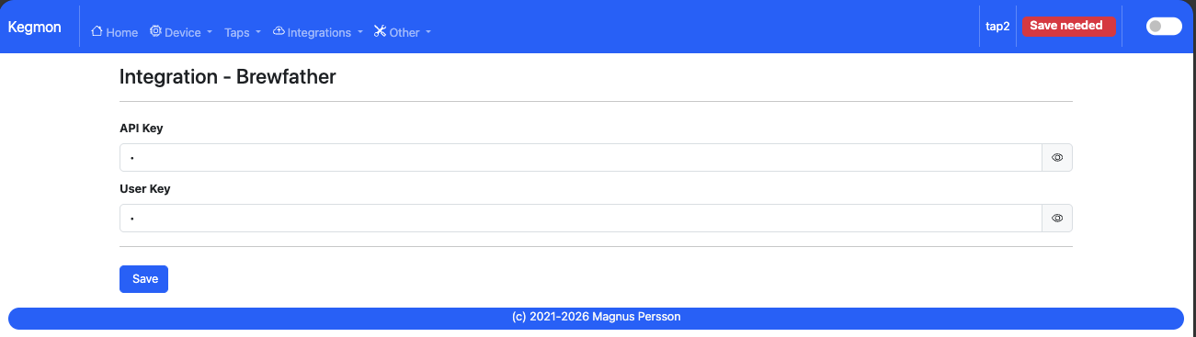
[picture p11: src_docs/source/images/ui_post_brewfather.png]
Brewfather integration


Enter API and user keys for Brewfather access.

Integration - Brewspy
*********************

Link to BrewSpy for keg and beer data.

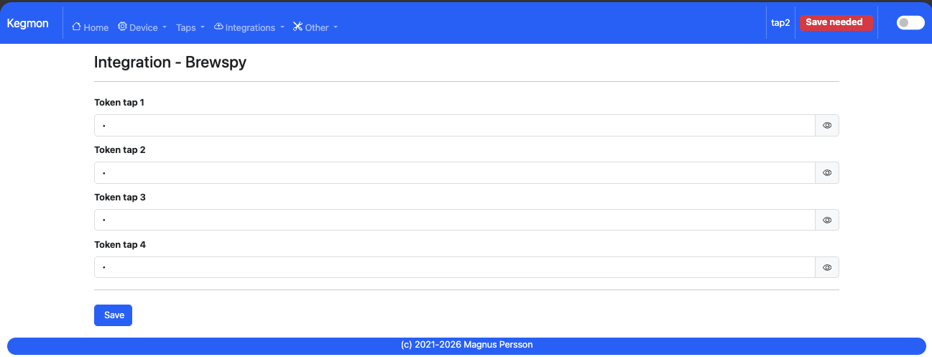
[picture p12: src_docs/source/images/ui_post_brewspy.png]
Brewspy integration


Enter tokens for kegs. Copy the webhook URL code from BrewSpy and paste it here.

Integration - Barhelper
***********************

Integrate with Barhelper for additional monitoring.

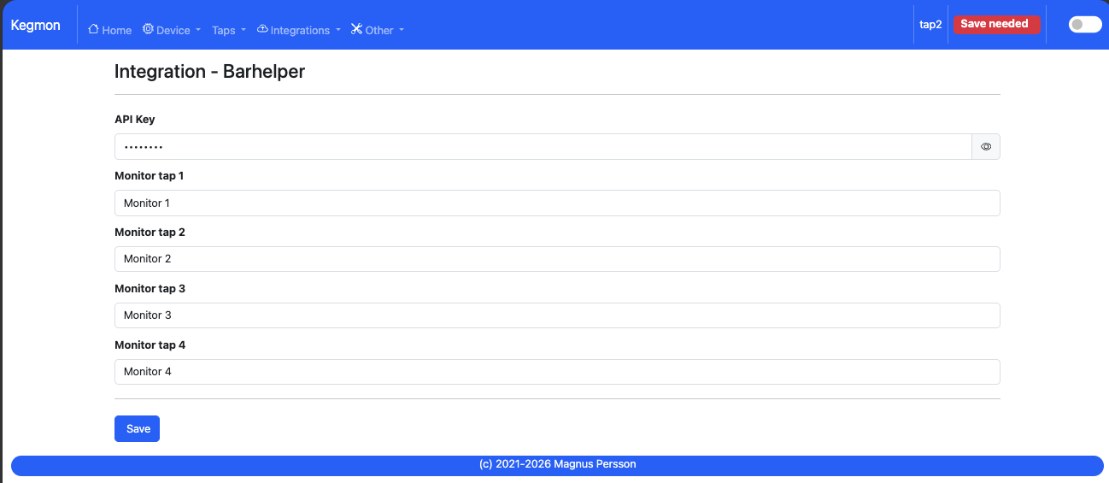
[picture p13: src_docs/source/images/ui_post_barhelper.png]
Barhelper integration


Enter API keys and monitor names. Obtain the key from Barhelper settings (save it securely, as it's not retrievable later). Monitors are added automatically on first run.

Integration - BrewLogger
************************

Enter the BrewLogger base URL. Keg state and pour information are sent to that
endpoint when the integration is configured.

Integration - Influx
********************

Send data to InfluxDB for analysis.

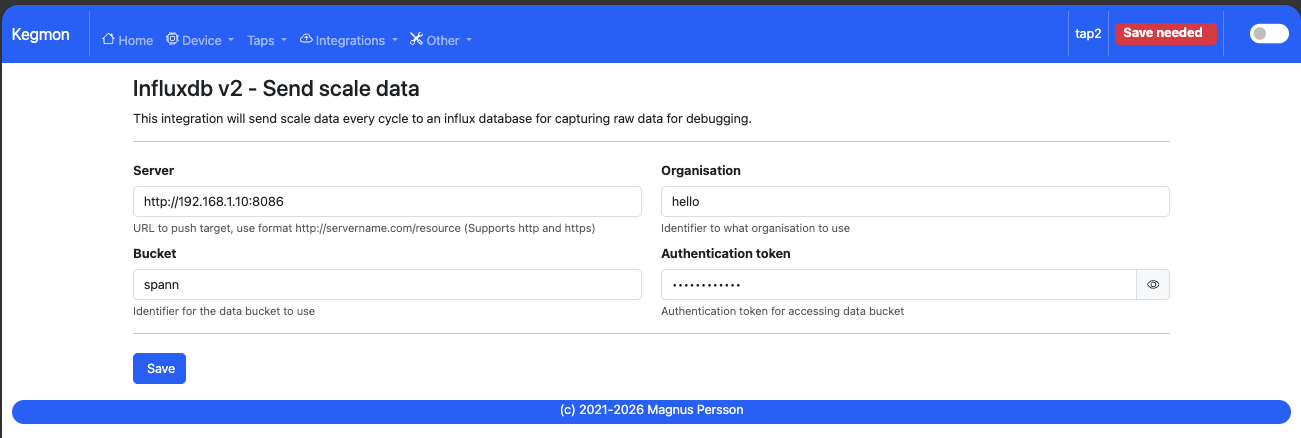
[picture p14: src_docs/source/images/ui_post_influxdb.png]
Influx integration


Configure InfluxDB v2 for logging scale and internal parameters. When enabled,
the firmware sends periodic data for all configured scales and records events.

Serial Console
**************

Access device logs for troubleshooting.

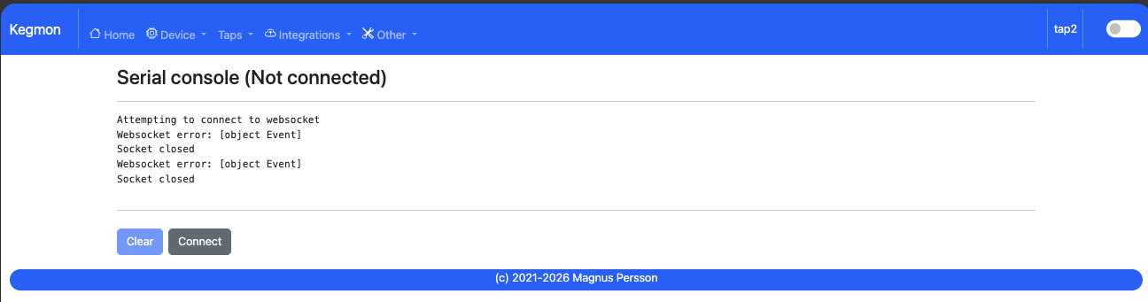
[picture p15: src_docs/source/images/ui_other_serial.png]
Serial console


View real-time serial output from the device.

Backup & Recovery
*****************

Manage configuration backups.

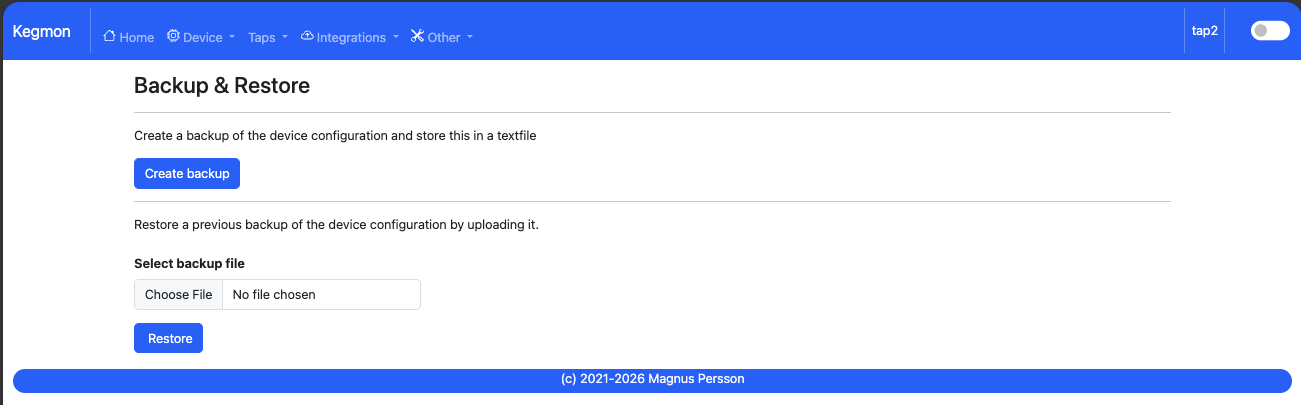
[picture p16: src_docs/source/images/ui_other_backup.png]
Backup configuration


Create a backup file from the current settings or restore a KegMon backup file.
Restoring replaces the corresponding configuration fields and saves them to the
device, so keep a known-good backup before experimenting.

Firmware Update
***************

Update device firmware over-the-air.

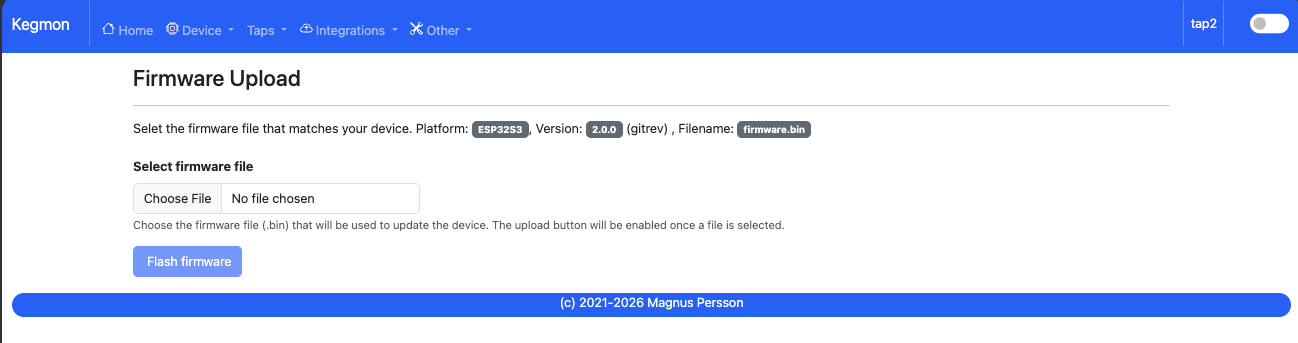
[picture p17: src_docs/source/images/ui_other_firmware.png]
Upload firmware


Upload the ``.bin`` firmware file that matches the device information shown on
the page. The device restarts after a successful upload.

Support
*******

Access diagnostic information.

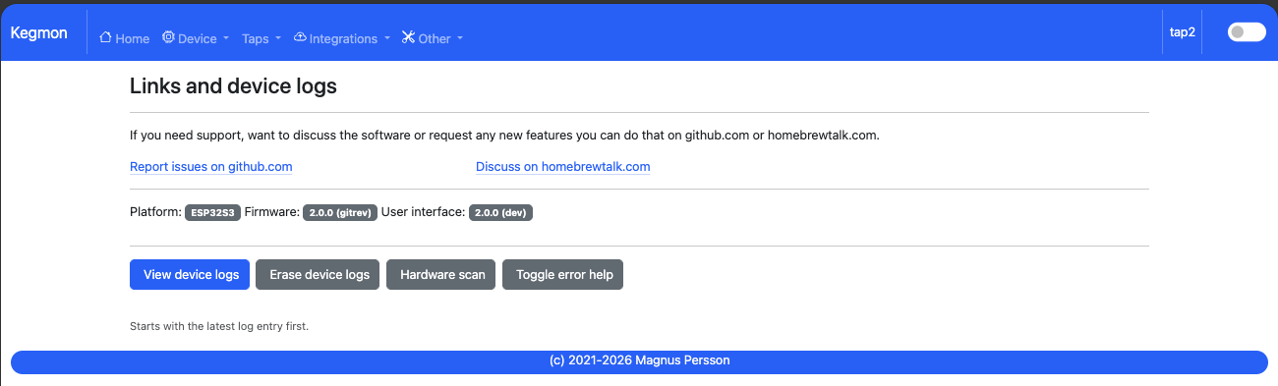
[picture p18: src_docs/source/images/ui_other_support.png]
Support information


View logs and hardware details.

Tools
*****

Interact with the device's file system.

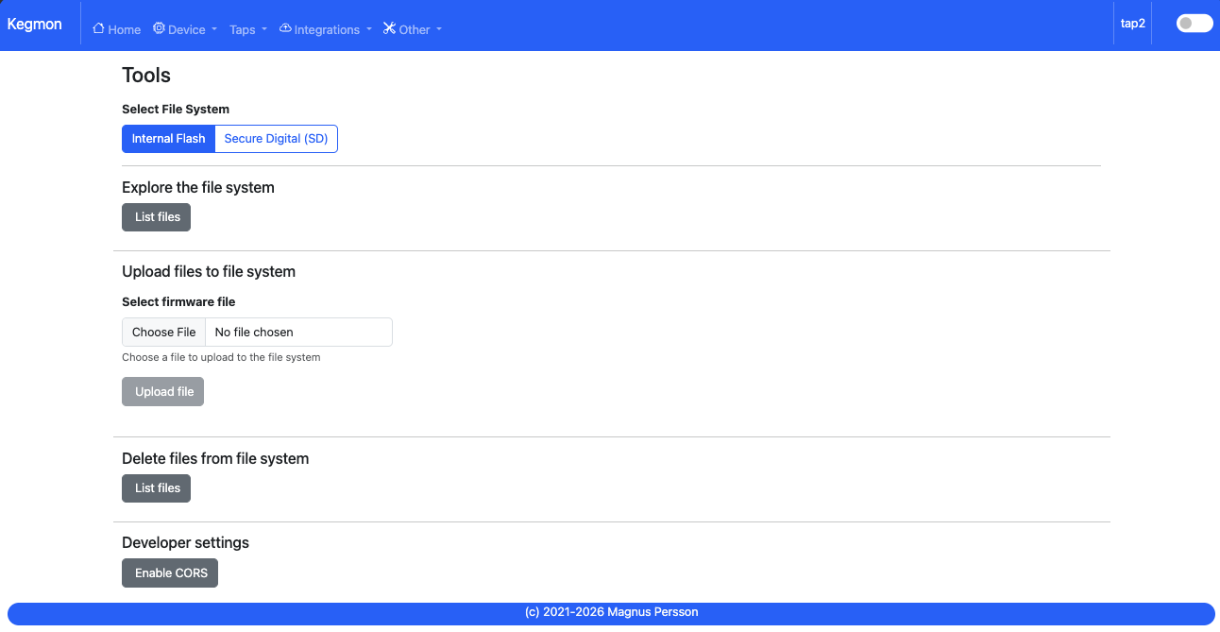
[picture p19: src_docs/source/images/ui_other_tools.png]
Tools


Manage files on the device.

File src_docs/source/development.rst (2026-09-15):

.. _development:

Development
===========

Contributing to KegMon2
-----------------------

KegMon is an ESP32-S3 Arduino/PlatformIO project. The web UI is a Vue 3/Vite
application in ``ui/``; its production assets are embedded in the firmware.
The documentation is built with Sphinx.

The native change-detection tests use GoogleTest and do not need a device.
PlatformIO environments provide the firmware and hardware-test builds.

Getting Started
---------------

To contribute:

1. Set up the development environment using the tools below.
2. Fork the repository and create a feature branch.
3. Run the relevant UI, native-test, documentation, or PlatformIO validation.
4. Submit a pull request with a clear description.

Required Tools
--------------

* **VS Code**: Primary code editor. Download from https://code.visualstudio.com/.
* **PlatformIO**: Extension for VS Code to handle Arduino ESP32 development. Install via VS Code marketplace or https://platformio.org/.
* **Git**: Version control. For Windows, use https://gitforwindows.org/; included with macOS/Linux.

Useful commands
~~~~~~~~~~~~~~~

Build the primary firmware target::

  pio run -e kegmon-esp32s3-pro-tft-sd

Run native change-detection tests::

  cd test && mkdir -p build && cd build && cmake .. && make && ./changedetection_integration_test

Build the web UI and copy its embedded assets::

  cd ui && npm run build
  cd .. && ./copy_ui.sh

Build the documentation::

  cd src_docs && make html

For more details, refer to the repository's README or issue tracker.

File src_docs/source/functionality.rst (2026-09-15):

.. _functionality:

Functionality
=============

KegMon is a comprehensive keg monitoring system designed for homebrewers, providing real-time tracking of beer levels, pours, and environmental conditions. Key features include:

* **Modern Web-Based Interface**

  A modern HTML5 web interface accessible from any device, enabling easy configuration of settings, real-time monitoring of keg status, and management of beer data without needing direct hardware access.

* **Graphical Interface on TFT Screen**

  An adaptive graphical user interface displayed on the device's TFT screen, which dynamically adjusts based on the number of installed scales to provide clear, intuitive navigation and data visualization.

* **3-Step Easy Scale Calibration**

  A straightforward 3-step calibration process performed entirely through the web interface: tare the scale to zero, calculate the calibration factor using a known weight, and verify accuracy for reliable measurements.

* **3D Printable Bases for Kegs**

  Includes 3D models for custom keg bases, or compatibility with other commercially available load cell bases, allowing flexible hardware setup for various keg sizes and types.

* **Hardware Support for Up to 4 Scales**

  Designed to support up to 4 scales simultaneously, with each scale capable of displaying real-time statistics on an attached display, enabling monitoring of multiple kegs in a single system.

* **Stable Level Detection and Keg Lifecycle States**

  Each scale has an independent state machine for settling, stable monitoring,
  pouring, keg absence/replacement, calibration-required, invalid readings and
  load-cell errors. A new baseline is committed only after the signal has
  settled, which avoids locking an intermediate post-pour weight.

* **Pour Detection and Event History**

  Dual-filter slope analysis detects realistic downward flow, tracks the pour,
  and records completion data. Events are available in the web interface; when
  SD-card support is enabled and the card mounts, persistent CSV event history
  is also available.

* **Volume Estimation**

  Calculates remaining beer volume in terms of glasses or pints, factoring in the keg's weight, final gravity, and the pre-configured weight of an empty keg for precise inventory management.

* **Home Assistant Integration**

  Seamlessly integrates with Home Assistant for automated data export, allowing users to view current beer selections, last pour details, remaining volume, and other metrics within their smart home dashboard.

* **BrewSpy Integration**

  Connects to BrewSpy to fetch and import brew data, automatically updating keg levels and beer information when batches are changed or new brews are added.

* **BrewLogger and Barhelper Integrations**

  Sends keg and pour information to the configured BrewLogger endpoint and can
  publish keg information to configured Barhelper monitors.

* **Brewfather Integration**

  Pulls data from Brewfather on recent brews, simplifying the import of batch details, recipes, and gravity readings for streamlined setup and tracking.

* **Easy Software Updates**

  Supports over-the-air software updates directly through the web UI, ensuring the device stays current with the latest features and bug fixes without physical access.

* **Temperature Sensors**

  Supports DS18B20 sensors on the shared OneWire bus. A sensor ID can be
  assigned to each tap for per-keg temperature display and integrations.

* **Backup and Restore of Settings**

  Allows full backup and restore of device configurations as JSON files, useful for recovery from hardware issues or replicating setups across multiple devices by editing the "id" fields to match each unit's unique ID (available on the index page).

* **Unit Preferences**

  Flexible unit selection for temperature (Celsius or Fahrenheit), weight (kg or lbs), and volume (cl, UK fl. oz, or US fl. oz), with all internal calculations using metric units (Celsius, kg, cl) and automatic conversion for display.

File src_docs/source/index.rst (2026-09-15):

.. KegMon documentation master file, created by
   sphinx-quickstart on Tue Jun  7 09:29:30 2022.
   You can adapt this file completely to your liking, but it should at least
   contain the root `toctree` directive.

Welcome to KegMon2 - Keg Level Monitor
--------------------------------------

.. note::
  Reflects the current v2.0.0 (alfa 1), last reviewed 2026-09-15.

Introduction
============

KegMon is an open-source keg monitoring system designed for homebrewers to track beer levels, pours, and environmental conditions in real-time. The software is tailored to personal needs and integrates with popular services like Brewfather, BrewSpy, and Home Assistant. Suggestions for additional integrations are welcome—feel free to raise requests on GitHub.

The system features two primary interfaces: a graphical TFT display on the device and a web-based interface accessible from any browser. It uses advanced filtering algorithms to compensate for the unpredictability of inexpensive load cells, ensuring stable and accurate readings.

To detect level changes, KegMon employs a dual-filter approach: a fast filter triggers the system into a "pouring" state upon initial weight changes, while slower filters validate the event by measuring the weight drop per second (slope). This helps distinguish genuine pours from minor fluctuations.

The system can handle multiple consecutive pours by stabilizing readings and
splitting larger pours using the configured glass size. It supports up to four
kegs and disables a scale for the session when its HX711 is not found at
startup.

The v2.0.0 update is backward-compatible with scales from previous versions, requiring only a controller upgrade. The project includes:

* Software for managing scales, processing readings, and providing interfaces.
* Hardware designs using standard HX711 AD converters, load cells, and temperature sensors.
* 3D models for keg bases and display enclosures.

Hardware Options
================

Board
*****

The current version exclusively supports the Lolin ESP32 S3 PRO board, which provides the dual-core processing needed for background tasks and advanced filtering. It includes an onboard SD card slot and connectors for the TFT display.

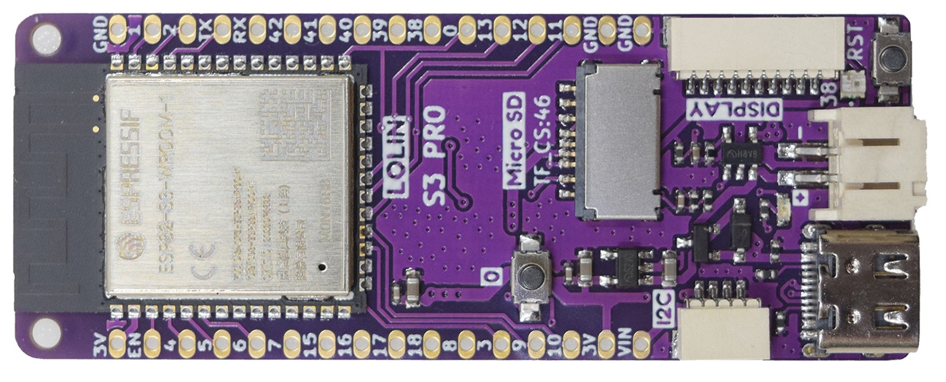
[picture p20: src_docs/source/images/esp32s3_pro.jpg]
ESP32 S3 PRO board


Display
*******

The current firmware builds support these TFT controller variants:

* ILI9341 at 240 x 320 pixels, with or without SD-card support.
* ILI9488 at 480 x 320 pixels, with SD-card support.

The Lolin 2.4-inch ILI9341 display is the documented reference display.

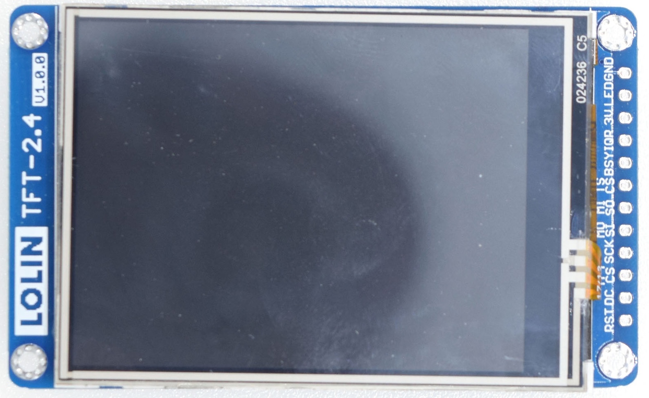
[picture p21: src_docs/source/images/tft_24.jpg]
Lolin TFT 2.4" display


HX711
*****

For the ADC (HX711 board), use a module whose pinout matches the controller
PCB. The firmware measures whether each detected HX711 is operating at 10 or
80 samples per second; it does not require a particular sampling-rate variant.

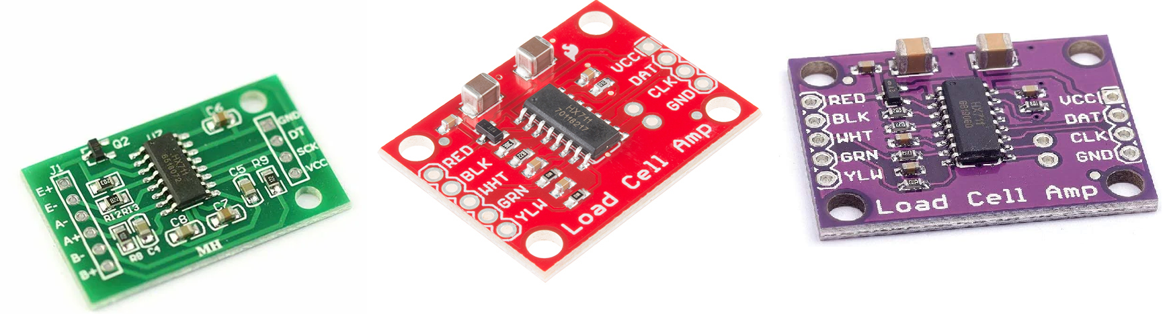
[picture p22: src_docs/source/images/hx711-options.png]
HX711 boards


Verify the module's pinout and wiring before powering the controller. A module
that does not respond during startup leaves that scale disabled.

Temperature Sensor
******************

The system supports DS18B20 one-wire temperature sensors, with the ability to use one per scale base for precise monitoring of each keg's environment.

Credits
=======
Thanks to the following projects and libraries that made KegMon possible:

* https://github.com/mp-se/espframework
* https://github.com/thijse/Arduino-Log
* https://github.com/bblanchon/ArduinoJson
* https://getbootstrap.com
* https://chartjs.org
* https://modelviewer.dev/
* https://github.com/pstolarz/OneWireNg
* https://github.com/pstolarz/Arduino-Temperature-Control-Library
* https://github.com/ESP32Async/ESPAsyncWebServer
* https://github.com/ESP32Async/AsyncTCP
* https://github.com/Bodmer/TFT_eSPI
* https://github.com/RobTillaart/HX711
* https://github.com/lvgl/lvgl

.. toctree::
   :maxdepth: 2
   :caption: Contents:

   functionality
   releases
   building
   installation
   configuration
   license
   development
   q_and_a

Indices and tables
==================

* :ref:`genindex`
* :ref:`modindex`
* :ref:`search`

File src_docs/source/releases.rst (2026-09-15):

.. _releases:

Releases 
########

v2.0.0 - alfa 1 
===============

* New redesigned hardware and PCB for supporting more than 2 scales (PCB v1.1 required)
* New scale reading and filtering engine to improve accuracy and pour detection. 
* Event based engine so now its possible to send notification to HA when entering pouring state or any other state.
* Upgraded depdendencies to latest versions

Current source configuration
----------------------------

The PlatformIO configuration identifies the current v2.0.0 build as ``alfa 1``.
This documentation tracks the source tree rather than a separately tagged
release artifact.

Dropped support for

* DHT22 and BME temperature sensors (use DS18B20 instead).
* LiquidCrystal I2C displays.
* OLED displays.
* ESP8266 and ESP32 mini boards

Not yet completed:

* BLE temperature sensor support
* Additional TFT display options

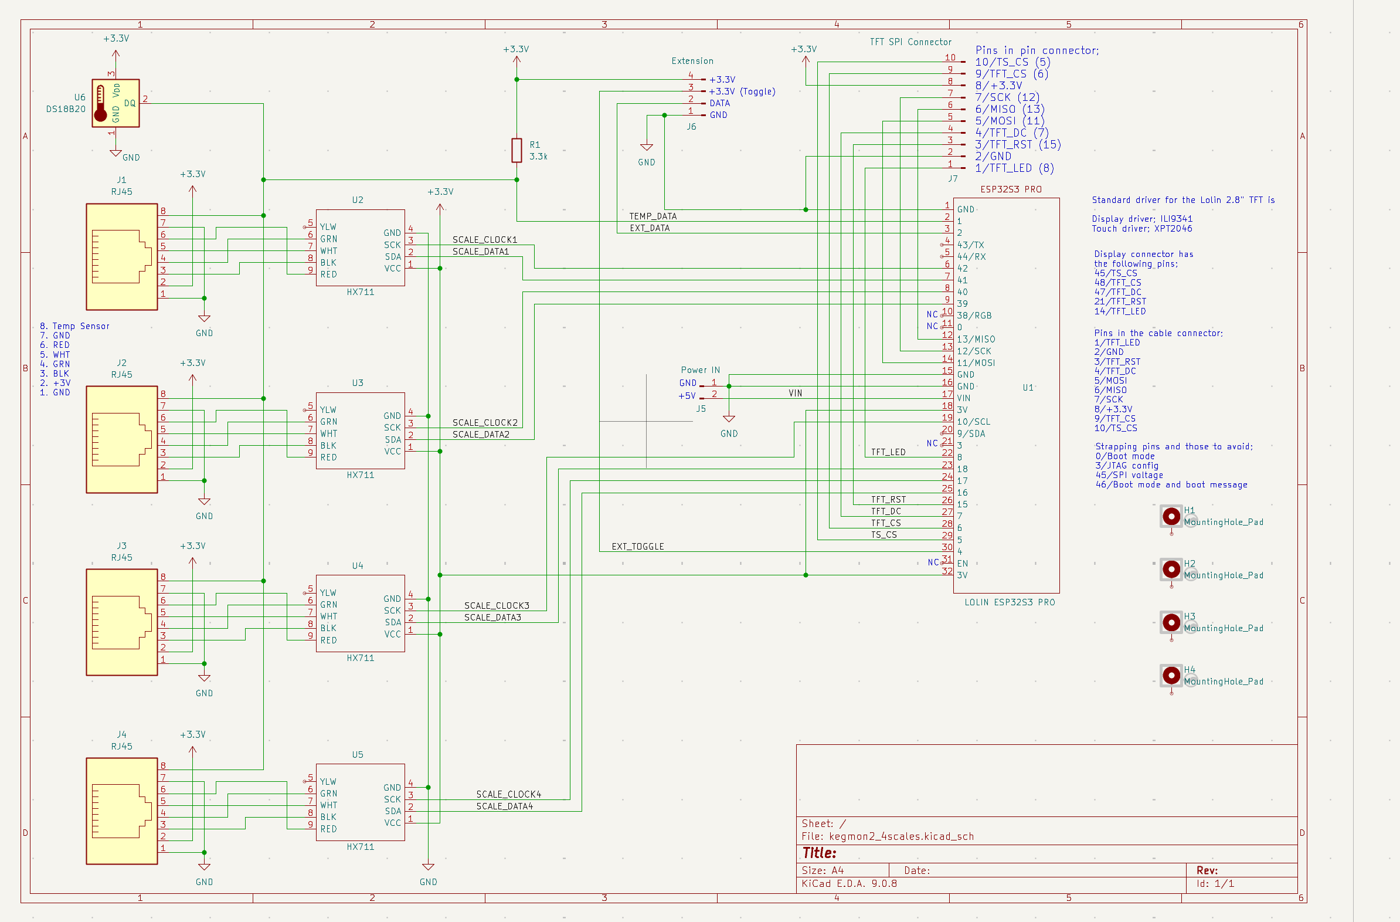
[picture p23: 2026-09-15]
src_docs/source/images/esp32s3_schema_4scales.png

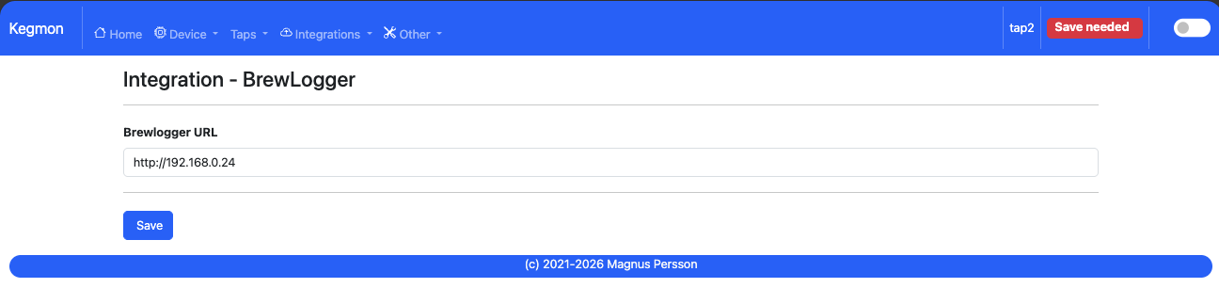
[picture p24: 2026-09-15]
src_docs/source/images/ui_post_brewlogger.png

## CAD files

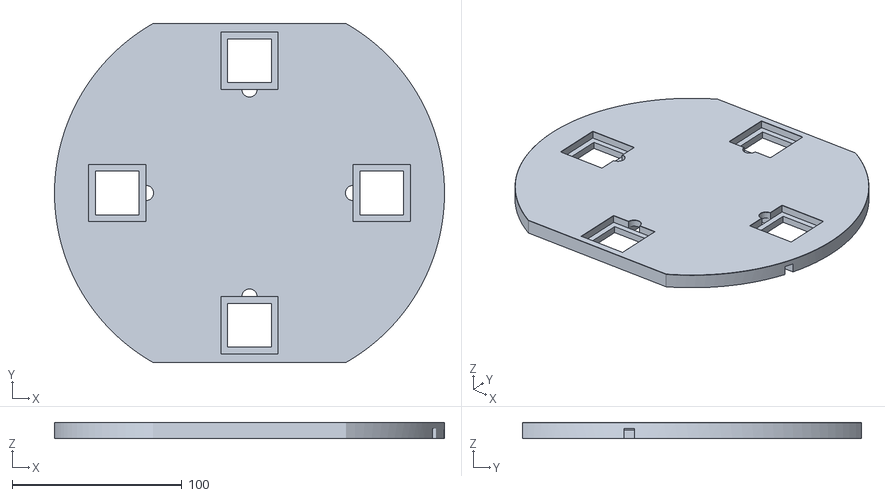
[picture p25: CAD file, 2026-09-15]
src_docs/source/3d/scale2_base.stl
230.0 x 200.0 x 9.50

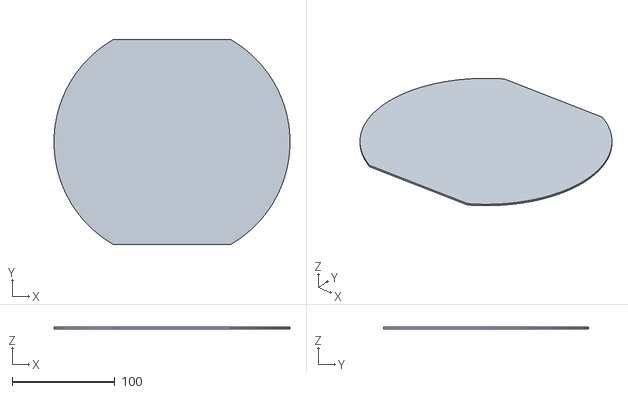
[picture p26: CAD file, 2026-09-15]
src_docs/source/_static/3d/scale2_base_cover.stl
229.9 x 200.0 x 1.50

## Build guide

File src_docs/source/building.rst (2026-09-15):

.. _building:

Building a device
=================

Step 1 - Build the scale bases
------------------------------

First you need to build the scale base. You will need the following parts per scale:

* DS18B20 temperature sensor
* Network cable 3-4m (one cable can be split to support 2 scales)
* Load cells (4 x 50kg)
* Scale base PCB 
* 3D Printed scale base

PCB for scale bases to make it easier connect all the cables. The PCB also has room for a RJ45 connector but in the 
current design of the scale bases its not used since it would make the scale base thicker.

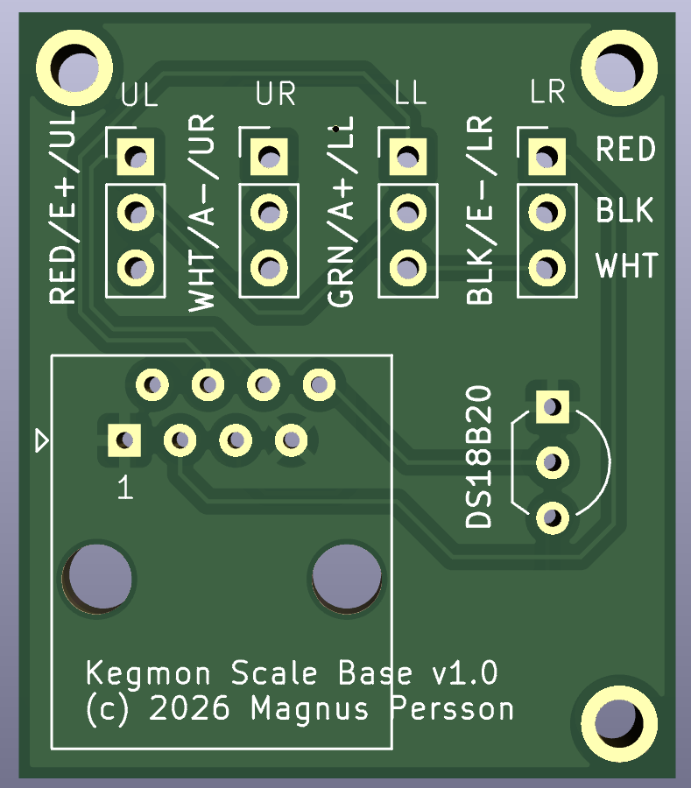
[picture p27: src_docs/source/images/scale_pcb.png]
PCB for connecting wires in scale base


Step 1.1 - Printing the scale base
^^^^^^^^^^^^^^^^^^^^^^^^^^^^^^^^^^

The 3D models for the scale bases are hosted in the `3d-designs <https://github.com/mp-se/3d-designs>`_ repository. You can view them interactively below.

.. raw:: html

   <script type="module" src="https://ajax.googleapis.com/ajax/libs/model-viewer/3.4.0/model-viewer.min.js"></script>
   <script type="module">
     const modelViewers = document.querySelectorAll("model-viewer");
     modelViewers.forEach(mv => {
       mv.addEventListener("load", () => {
         const materials = mv.model.materials;
         materials.forEach(material => {
           material.pbrMetallicRoughness.setBaseColorFactor([0.2, 0.5, 0.8, 1.0]);
         });
       });
     });
   </script>
   <div style="display: flex; flex-wrap: wrap; gap: 20px;">
     <div style="flex: 1; min-width: 300px;">
       <h4>Scale base</h4>
       <model-viewer src="_static/3d/scale2_base.glb" 
                     style="width: 100%; height: 300px; background-color: #fafafa;" 
                     auto-rotate camera-controls shadow-intensity="1">
       </model-viewer>
     </div>
     <div style="flex: 1; min-width: 300px;">
       <h4>Scale base cover</h4>
       <model-viewer src="_static/3d/scale2_base_cover.glb" 
                     style="width: 100%; height: 300px; background-color: #fafafa;" 
                     auto-rotate camera-controls shadow-intensity="1">
       </model-viewer>
     </div>
   </div>

Step 1.2 - Mount the load cells
^^^^^^^^^^^^^^^^^^^^^^^^^^^^^^^

Start with mounting in the loadcells in the printed base and make sure the cables are ready for soldering on the scale base PCB.

Step 1.3 - Wire the load cells and temperature sensor
^^^^^^^^^^^^^^^^^^^^^^^^^^^^^^^^^^^^^^^^^^^^^^^^^^^^^

Mount and solder the temperature sensor on the scale base PCB as indicated by the silkscreen. Only DS18B20 sensors with 3 
wires are supported since all the temperature sensors share the same onewire bus.

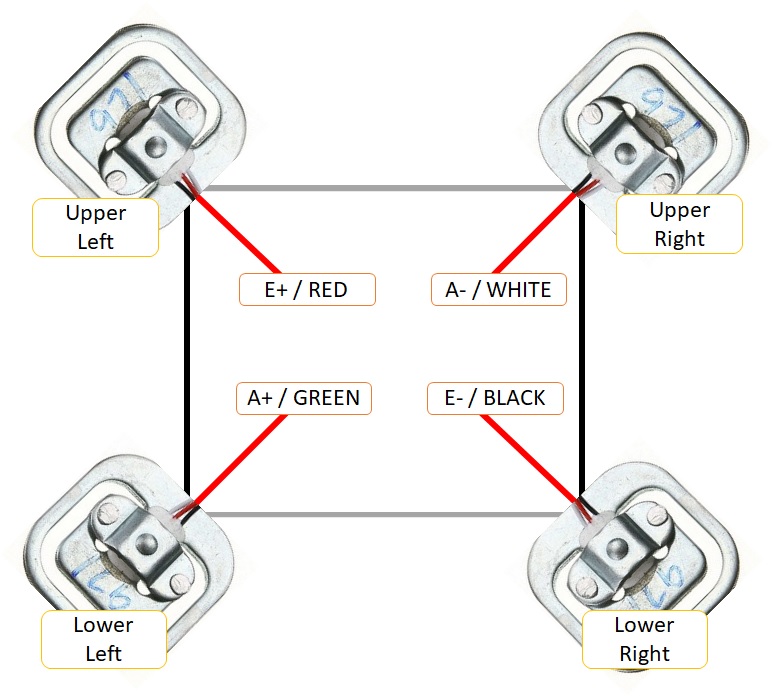
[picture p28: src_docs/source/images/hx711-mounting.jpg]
How to wire load cells


Mark the load cells acording to this schematic and solder the cables in the position indicated on the PCB, 
one row per load cell. If the cabels are to long make sure you **cut them to the same length**. Use UL (Upper Left), UR (Upper Right),
LL (Lower Left) and LR (Lower Right) to identify the cables. They should then be soldered to the PCB as shown on the silkscreen

Step 1.4 - Solder the network cable
^^^^^^^^^^^^^^^^^^^^^^^^^^^^^^^^^^^

In order for the scale bases to be as thin as possible i dont use the RJ45 connector on the scale, instead 
solder the cables directly to the PCB using the following color scheme. Pin 1 is marked on the PCB.

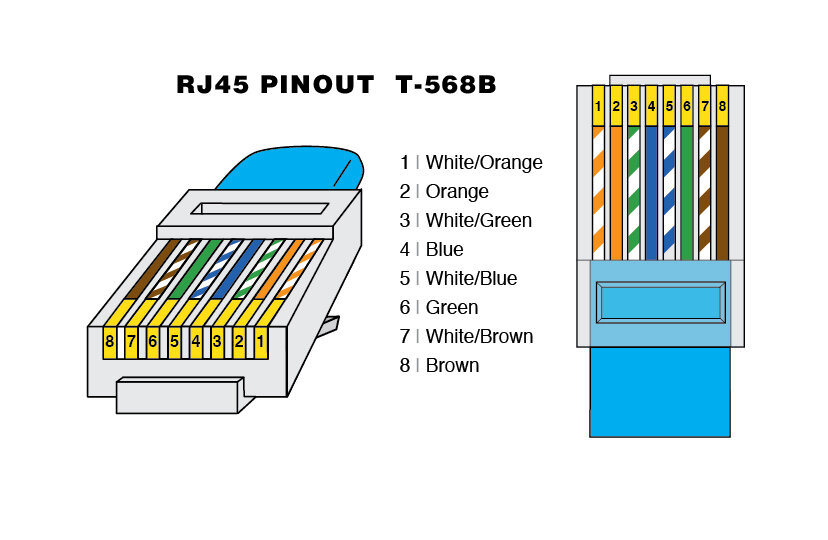
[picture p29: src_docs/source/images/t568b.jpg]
Cable colors in T568B standard


I usually put some tejp over the soldered connected to keep the cables in position when closing the scale base.

Step 1.4 - Validate scale base
^^^^^^^^^^^^^^^^^^^^^^^^^^^^^^

Before closing the scale base its a good idea to validate that everything works, so connect 
it to the controller and calibrate it before continuing to the last step.

Step 1.5 - Glue the base cover
^^^^^^^^^^^^^^^^^^^^^^^^^^^^^^

.. note::
  Don't glue the base togehter before you have validated that it works as intended.

Put some glue around on the scale base and push the cover in place, make sure its aligned. Use any adhesive 
that works with plastics.

Step 2 - Build the controller
-----------------------------

First you need to build the hardware which consists of 1 to 4 scale bases, case with the displays, HX711 boards 
and the ESP32. You will need the following parts. If you only want 2 scales just add 2 HX711 boards and 2 
scale bases. If the software does not find an ADC it will disable that scale.

* ESP32 S3 PRO board (Lolin)
* HX711 boards (Purple or Red)
* TFT display (Lolin 2.4" recommended)
* RJ45 connectors
* 3.3kOhm resistor for DS18B20
* Controller PCB for ESP32 and display
* 3D Printed case for display and ESP32
* SD card 2Gb+ (optional for logging)

PCB for 4 scales and display

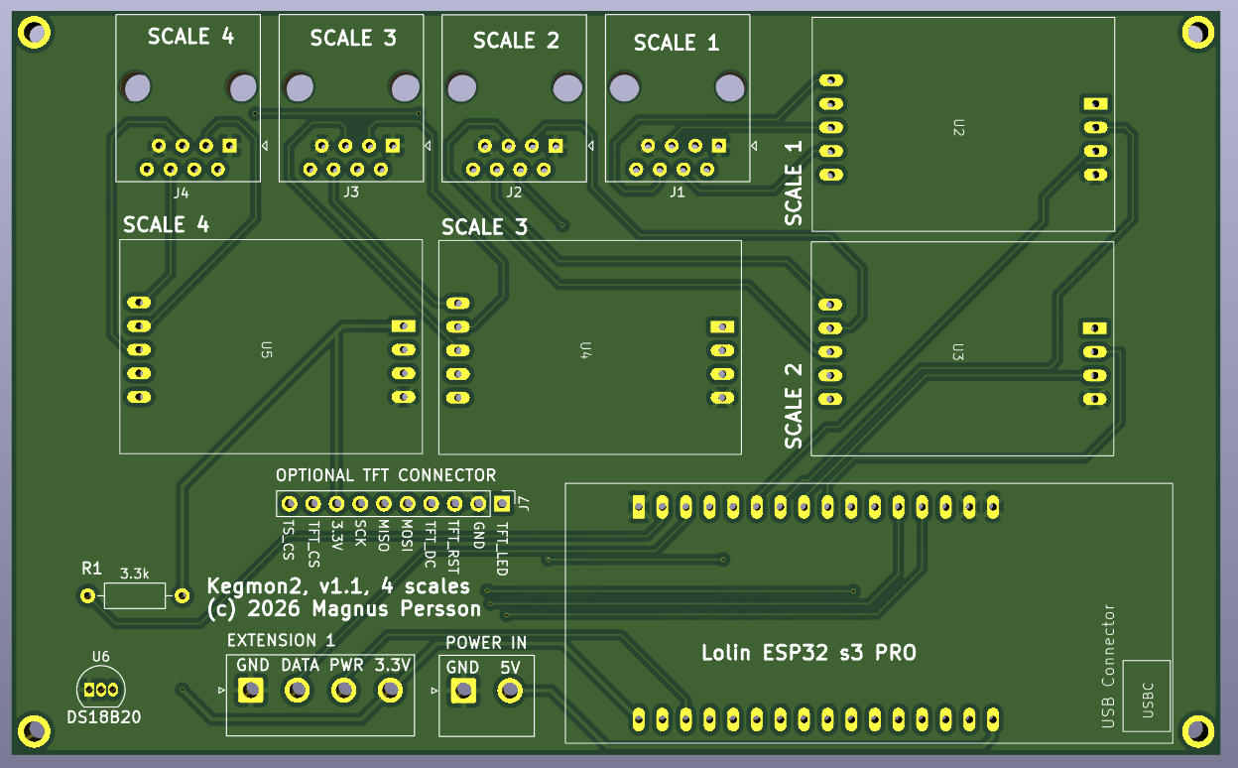
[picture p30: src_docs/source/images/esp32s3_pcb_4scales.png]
PCB for ESP32 and display


There are some pins marked EXTENSION and they are reserved for future use and not used in this version.

Step 2.1 - Solder the connectors
^^^^^^^^^^^^^^^^^^^^^^^^^^^^^^^^

.. note::
  The marked DS18B20 is an extension where you can add an extra temperature sensor if 
  you dont want to add them to the scale bases. The areas marked EXTENSION is not yet 
  in use and is for future use.

TBD

Step 2.2 - Solder pins on HX711 boards and ESP32
^^^^^^^^^^^^^^^^^^^^^^^^^^^^^^^^^^^^^^^^^^^^^^^^

TBD

Step 2.3 - Mount the components
^^^^^^^^^^^^^^^^^^^^^^^^^^^^^^^

TODO

Step 2.4 - Connect the display
^^^^^^^^^^^^^^^^^^^^^^^^^^^^^^

If you are using the Lolin 2.4" display and their cable the connection is simple. But 
if you are using another display then i recommend to buy the lolin cable and then cut / solder the other end to your display.

The following display builds are currently supported:

* ILI9341-based displays (240 x 320), with or without an SD card.
* ILI9488-based displays (480 x 320), with an SD card.

Use the firmware binary that matches the TFT controller and wiring. The
ILI9341 Lolin 2.4-inch display is the reference configuration described here.

Step 2.5 - 3D print the case
^^^^^^^^^^^^^^^^^^^^^^^^^^^^

TODO

Step 3 - Flash the device
-------------------------

The first step is to flash the firmware, I recommend using my webflasher as the easy option. Detailed 
instructions can be found here :ref:`installation`

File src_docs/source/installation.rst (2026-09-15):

.. _installation:

Software Installation
---------------------

This guide covers installing and setting up KegMon on your ESP32 device, including flashing firmware, configuring WiFi, and accessing the interface.

GravityMon Web Flasher
======================

The GravityMon Web Flasher supports flashing firmware for various projects, including KegMon, and allows WiFi configuration over a serial connection. Access it here: `GravityMon Web Flasher <https://www.gravitymon.com/flasher/index.html/>`_.

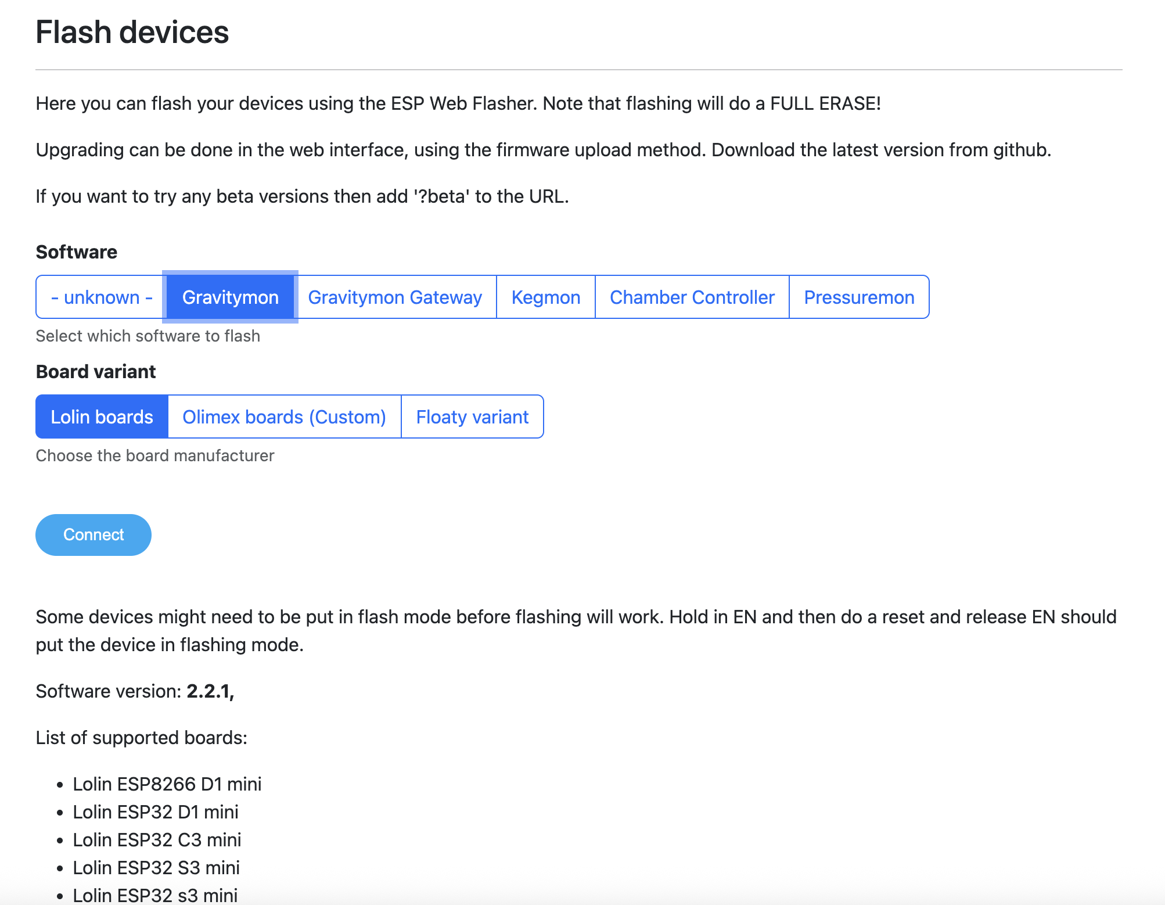
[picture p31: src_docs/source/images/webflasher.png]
Web flasher interface


Select the software to flash and the board manufacturer; the flasher will automatically use the correct binaries.

.. warning::

  Using the web flasher erases the entire device before flashing, so back up your settings first. For upgrades, use the firmware update feature within the KegMon software.

Firmware Update from the Web UI
*******************************

For normal upgrades, open the KegMon web interface and select **Other >
Firmware update**. The page shows the expected firmware filename; choose the
matching ``.bin`` file and wait for the device to restart. This preserves the
configuration, unlike a full erase-and-flash operation.

.. _serial_monitoring:

Serial Monitoring
=================

To view logs and output from the device, use a serial monitoring tool. For Windows, a simple option is the "Serial Port Monitoring" app from the Microsoft Store. Set the baud rate to 115200, 8N1.

For macOS or Linux, tools like `screen` or `minicom` can be used. For example, with `screen`: ``screen /dev/tty.usbserial-XXXX 115200`` (replace with your serial port).

.. _setup_wifi:

WiFi Compatibility
==================

The ESP32 has limited WiFi support and relies on older standards. Consider these guidelines for setup:

* Only 2.4GHz bands are supported, with channels 1-13 (in 802.11 b/g/n modes).
* Channels should be in the 20-25 MHz range.
* The SSID must be visible (hidden SSIDs do not work).

For more details, refer to: https://www.espressif.com/sites/default/files/esp8266_wi-fi_channel_selection_guidelines.pdf

Configuring WiFi
================

After flashing, the device needs WiFi configuration. If previous software was installed, settings may already exist.

To enter WiFi setup mode on a configured device, use the board reset button
twice within the configured double-reset window.

If unconfigured, the device creates a wireless access point named `GravityMon` with the default password `password`. Connect to this AP, and the configuration page should open automatically. If not, navigate to **http://192.168.4.1** in your browser.

Enter your desired SSID and password. WiFi settings can also be adjusted later under Device > WiFi in the menu.

.. _setup_ip:

Finding the Device Address
==========================

Once WiFi is configured, the device reboots and connects to your network. A flashing blue LED indicates it's ready.

If your system supports mDNS, use the device's network name (e.g., kegmon.local) in your browser. Windows has limited mDNS support, so if issues arise:

* Check your router's admin panel for the device's IP address (e.g., http://192.168.1.56).
* Use an IP scanner or port scanner (available for Windows, macOS, or mobile) to find devices listening on port 80.

Once connected to the web interface, proceed with configuration.

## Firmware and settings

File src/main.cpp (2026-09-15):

/*
 * KegMon
 * Copyright (c) 2022-2026 Magnus
 *
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
 * Alternatively, this software may be used under the terms of a
 * commercial license. See LICENSE_COMMERCIAL for details.
 *
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
 */
#include <freertos/FreeRTOS.h>
#include <freertos/task.h>

#include <changedetection.hpp>
#include <display.hpp>
#include <event_logger.hpp>
#include <kegconfig.hpp>
#include <kegpush.hpp>
#include <kegwebhandler.hpp>
#include <looptimer.hpp>
#include <main.hpp>
#include <ota.hpp>
#include <scale.hpp>
#include <sdcard_mmc.hpp>
#include <sdcard_sd.hpp>
#include <serialws.hpp>
#include <temp_mgr.hpp>
#include <uptime.hpp>
#include <utils.hpp>
#include <weightvolume.hpp>
#include <wificonnection.hpp>
#if defined(ESP32S3)
#include <esp32s3/rom/rtc.h>
#endif
#include <esp_core_dump.h>

#include <cstdio>

void checkCoreDump();
void dumpDataToInfluxDB();

SerialDebug mySerial(115200L);
KegConfig myConfig(CFG_MDNSNAME, CFG_FILENAME);
WifiConnection myWifi(&myConfig, CFG_APPNAME, "password", CFG_MDNSNAME);
OtaUpdate myOta(&myConfig, CFG_APPVER);
KegWebHandler myWebHandler(&myConfig);
KegPushHandler myPush(&myConfig);
Display myDisplay;
TempSensorManager myTemp;
SerialWebSocket mySerialWebSocket;
Scale myScale;
ChangeDetection myChangeDetection;
LoopTimer sdTimer(10 * 1000);
LoopTimer displayTimer(100);
LoopTimer loopTimer(2000);
RunMode runMode = RunMode::normalMode;
#if defined(ENABLE_MMC)
SdCardMMC mySdStorage;
#elif defined(ENABLE_SD)
SdCardSD mySdStorage;
#endif

/**
 * Background task for scale reading and change detection updates
 * Runs on Core 1:
 *  - Reads all scales continuously and updates change detection state machine
 *  - Runs as fast as possible (limited only by HX711 sensor readiness)
 */
void scaleDetectionTask(void *parameter) {
  Log.notice(F("ScaleTask: Started on core %d" CR), xPortGetCoreID());

  // Fire system startup event to mark the beginning of a monitoring session
  myChangeDetection.fireStartupEvent(millis());

  while (true) {
    uint32_t currentTimeMs = millis();

    for (int i = 0; i < MAX_SCALES; i++) {
        UnitIndex idx = static_cast<UnitIndex>(i);
        // Only read and update if the ADC hardware was found during setup
        if (myScale.isConnected(idx)) {
            ScaleReadingResult res = myScale.read(idx);
            myChangeDetection.update(idx, res, currentTimeMs);
        }
    }

    // Process any scheduled tare or calibration operations
    myScale.loop();

    dumpDataToInfluxDB();

    // Yield to other tasks (display, etc.)
    vTaskDelay(pdMS_TO_TICKS(10));
  }
}

TaskHandle_t scaleTaskHandle = nullptr;

void setup() {

  delay(2000);  // Wait for stable power

  // see: rtc.h for reset reasons
  Log.notice(F("Main: Reset reason %d." CR), rtc_get_reset_reason(0));
  Log.notice(F("Core dump check %d." CR), esp_core_dump_image_check());

  char cbuf[30];
  uint32_t chipId = 0;
  for (int i = 0; i < 17; i = i + 8) {
    chipId |= ((ESP.getEfuseMac() >> (40 - i)) & 0xff) << i;
  }
  snprintf(&cbuf[0], sizeof(cbuf), "%6x", chipId);
  Log.notice(F("Main: Started setup for %s." CR), &cbuf[0]);
  Log.notice(F("Main: Build options: %s (%s) LOGLEVEL %d " CR), CFG_APPVER,
             CFG_GITREV, LOG_LEVEL);

  myConfig.checkFileSystem();
  myConfig.loadFile();
  myConfig.setWifiScanAP(true);

  myDisplay.setup();
  myDisplay.setFont(FontSize::FONT_12);
  myDisplay.printLineCentered(1, "Kegmon v2");
  myDisplay.printLineCentered(3, "Starting");
  myWifi.init();
  delay(200);
  myScale.setup();

  // If ADC hardware is missing, permanently disable the scale unit in change detection
  for (int i = 0; i < MAX_SCALES; i++) {
    if (!myScale.isConnected(static_cast<UnitIndex>(i))) {
      myChangeDetection.disableUnit(static_cast<UnitIndex>(i));
    }
  }

#if defined(ENABLE_MMC)
  myDisplay.printLineCentered(3, "Mounting SD (SD_MMC) card");
  Log.notice(F("Main: MMC_CLK %d." CR), MMC_CLK);
  Log.notice(F("Main: MMC_CMD %d." CR), MMC_CMD);
  Log.notice(F("Main: MMC_D0 %d." CR), MMC_D0);
  mySdStorage.begin(MMC_CLK, MMC_CMD, MMC_D0);
#endif

#if defined(ENABLE_SD)
  myDisplay.printLineCentered(3, "Mounting SD (SD) card");
#if defined(ENABLE_TFT)
  mySdStorage.begin(SD_CS, myDisplay.getSPI());
#else
  mySdStorage.begin(SD_CS, SPI);
#endif  // ENABLE_TFT
#endif  // ENABLE_SD

  // Initialize event logger
  myEventLogger.init();

  // No stored config, move to portal
  if (!myWifi.hasConfig() || myWifi.isDoubleResetDetected()) {
    Log.notice(
        F("Main: Missing wifi config or double reset detected, entering wifi "
          "setup." CR));
    myDisplay.printLineCentered(3, "Entering WIFI Setup");
    myWifi.enableImprov(true);
    myWifi.startAP();
    runMode = RunMode::wifiSetupMode;
  }

  switch (runMode) {
    case RunMode::normalMode:
      myDisplay.printLineCentered(3, "Connecting to WIFI");
      myWifi.connect();
      myWifi.timeSync();
      break;

    case RunMode::wifiSetupMode:
      break;
  }

  checkCoreDump();

  myWebHandler.setupWebServer();
  mySerialWebSocket.begin(myWebHandler.getWebServer(), &EspSerial);
  mySerial.begin(&mySerialWebSocket);
  myTemp.setup();

  Log.notice(F("Main: Setup completed." CR));

  switch (runMode) {
    case RunMode::normalMode: {
      // Show the connected sensors on the display
      char buf[40];
      snprintf(&buf[0], sizeof(buf), "Temperature sensors: %d",
               myTemp.getSensorCount());
      myDisplay.printLineCentered(3, &buf[0]);

      for (int i = 0; i < MAX_SCALES; i++) {
        snprintf(&buf[0], sizeof(buf), "Scale %d: Connected=%s", i + 1,
                 myScale.isConnected((UnitIndex)i) ? "yes" : "no");
        myDisplay.printLineCentered(4 + i, &buf[0]);
      }

      // Launch background task for scale reading and change detection on Core 1
      Log.notice(F("Main: Launching scale detection task on core 1" CR));
      xTaskCreatePinnedToCore(scaleDetectionTask,    // Task function
                              "ScaleDetectionTask",  // Task name
                              4096,                  // Stack size (4KB)
                              nullptr,               // Task parameter
                              1,  // Priority (0=idle, higher=more important)
                              &scaleTaskHandle,  // Task handle output
                              1);                // Core ID (0=PRO, 1=APP)

      myTemp.read();
      delay(3000);

      // Choose display layout based on number of connected scales
      myDisplay.createUI(myScale.getConnectedScaleCount() > 2 ? 0 : 1);
    } break;

    case RunMode::wifiSetupMode:
      break;
  }

#if defined(INJECT_TEST_EVENT)
  Log.notice(F("Main: Injecting test events." CR));
  delay(2000);
  myChangeDetection.injectTestEvents();
#endif // INJECT_TEST_EVENT
}

void loop() {
  if (!myWifi.isConnected() && runMode == RunMode::normalMode) myWifi.connect();

  myUptime.calculate();
  myWebHandler.loop();
  myWifi.loop();
  mySerialWebSocket.loop();

  // Consume events from change detection and queue for web status publishing
  ChangeDetectionEvent event;
  if (myChangeDetection.getNextEvent(event)) {
  // while (myChangeDetection.getNextEvent(event)) {
    // Log event to SD card
    myEventLogger.logEvent(event);

    // Send the event to the web server for publishing
    myWebHandler.queueEvent(event);

    // Send the event to the TFT display for processing
    myDisplay.setScaleEvent(event.unitIndex, event.type);

    // Process the events if needed
    switch (event.type) {
      case ChangeDetectionEventType::SYSTEM_STARTUP:
        break;

      case ChangeDetectionEventType::STABLE_LEVEL: {
        // Fetch temperature for this scale
        float tempC = myTemp.getLastTempByIdC(myConfig.getTempSensorId(event.unitIndex));
        
        // Calculate glasses from stable volume
        WeightVolumeConverter volumeConverter(event.unitIndex);
        float stableVolume = volumeConverter.weightToVolume(event.stable.stableWeightKg);
        float glasses = stableVolume / myConfig.getGlassVolume(event.unitIndex);
        
        // Push keg information to integrations
        myPush.pushKegInformation(event.unitIndex, stableVolume,
                                  0.0f, glasses, tempC);
        
        // Push event state to Home Assistant
        myPush.getHomeAssist()->sendEventState(event.unitIndex, event.type);
        break;
      }

      case ChangeDetectionEventType::POURING:
        // Push event state to Home Assistant
        myPush.getHomeAssist()->sendEventState(event.unitIndex, event.type);
        break;

      case ChangeDetectionEventType::POUR_COMPLETED: {
        // Fetch temperature for this scale
        float tempC = myTemp.getLastTempByIdC(myConfig.getTempSensorId(event.unitIndex));
        
        // Push pour information to integrations
        myPush.pushPourInformation(event.unitIndex, event.pour.prePourWeightKg,
                                   event.pour.pourVolumeL, tempC);
        
        // Push event state to Home Assistant
        myPush.getHomeAssist()->sendEventState(event.unitIndex, event.type);
        break;
      }

      case ChangeDetectionEventType::KEG_REMOVED:
        // Clear Brewspy tap data
        myPush.getBrewspy()->clearKegInformation(event.unitIndex);
        
        // Push event state to Home Assistant
        myPush.getHomeAssist()->sendEventState(event.unitIndex, event.type);
        break;

      case ChangeDetectionEventType::KEG_REPLACED:
        // Push event state to Home Assistant
        myPush.getHomeAssist()->sendEventState(event.unitIndex, event.type);
        break;

      case ChangeDetectionEventType::INVALID_WEIGHT:
        // Push event state to Home Assistant
        myPush.getHomeAssist()->sendEventState(event.unitIndex, event.type);
        break;

      case ChangeDetectionEventType::LOAD_CELL_ERROR:
        // Push event state to Home Assistant
        myPush.getHomeAssist()->sendEventState(event.unitIndex, event.type);
        break;

      case ChangeDetectionEventType::LOAD_CELL_RECOVERED:
        Log.notice(
            F("Loop: Load cell recovered, reinitializing temperature "
              "sensors." CR));
        myTemp.setup();
        
        // Push event state to Home Assistant
        myPush.getHomeAssist()->sendEventState(event.unitIndex, event.type);
        break;

      case ChangeDetectionEventType::CALIBRATION_NEEDED:
        // Push event state to Home Assistant
        myPush.getHomeAssist()->sendEventState(event.unitIndex, event.type);
        break;

      case ChangeDetectionEventType::SETTLING_STARTED:
      case ChangeDetectionEventType::WEIGHT_CHANGE_DETECTED:
      case ChangeDetectionEventType::KEG_ABSENT_TIMEOUT:
      case ChangeDetectionEventType::SENSOR_RECOVERED:
      case ChangeDetectionEventType::CALIBRATION_COMPLETE:
        // These events are informational; push state to Home Assistant
        myPush.getHomeAssist()->sendEventState(event.unitIndex, event.type);
        break;
    }
  }

  // Handle SD card mount retries
  if (sdTimer.hasExpired()) {
    sdTimer.reset();
#if defined(ENABLE_MMC)
    if (!mySdStorage.hasCard()) {
      Log.notice(F("Loop: SD card not mounted, retry mounting." CR));
      mySdStorage.end();
      mySdStorage.begin(MMC_CLK, MMC_CMD, MMC_D0);
    }
#endif

#if defined(ENABLE_SD)
    if (!mySdStorage.hasCard()) {
      Log.notice(F("Loop: SD card not mounted, retry mounting." CR));
      mySdStorage.end();
#if defined(ENABLE_TFT)
      mySdStorage.begin(SD_CS, myDisplay.getSPI());
#else
      mySdStorage.begin(SD_CS, SPI);
#endif  // ENABLE_TFT
    }
#endif  // ENABLE_SD
  }

  // Update data for the display
  if (displayTimer.hasExpired()) {
    displayTimer.reset();

    char info[100];

#if defined(ENABLE_SD) && defined(ENABLE_LVGL)
    snprintf(info, sizeof(info), "ssid: %s ip: %s rssi: %d %s",
             WiFi.SSID().c_str(), WiFi.localIP().toString().c_str(),
             WiFi.RSSI(), mySdStorage.hasCard() ? LV_SYMBOL_SD_CARD : "");
#else
    snprintf(info, sizeof(info), "ssid: %s ip: %s rssi: %d",
             WiFi.SSID().c_str(), WiFi.localIP().toString().c_str(),
             WiFi.RSSI());
#endif
             myDisplay.setStatus(info);

    // Set format and theme once (global display settings)
    myDisplay.setDisplayUnit(myConfig.getVolumeUnit(),
                             String(myConfig.getTempUnit()).c_str());
    myDisplay.setTheme(myConfig.getDarkMode());

    for (int i = 0; i < MAX_SCALES; i++) {
      UnitIndex idx = static_cast<UnitIndex>(i);

      float t = myTemp.getLastTempByIdC(myConfig.getTempSensorId(idx));
      if (!isnan(t)) t = myConfig.isTempUnitC() ? t : convertCtoF(t);

      float w = myChangeDetection.getStableWeight(idx);
      w = isnan(w) ? 0 : (myConfig.isWeightUnitKG() ? w : convertKGtoLBS(w));

      float v = myChangeDetection.getStableVolume(idx);
      v = isnan(v) ? 0 : (v * 100.0f);  // Convert from liters to centiliters
      v = myConfig.isVolumeUnitCL()
              ? v
              : (myConfig.isVolumeUnitUKOZ() ? convertCLtoUKOZ(v)
                                             : convertCLtoUSOZ(v));

      float p = myChangeDetection.getLastPourVolume(idx);
      p = p * 100.0f;  // Convert from liters to centiliters
      p = myConfig.isVolumeUnitCL()
              ? p
              : (myConfig.isVolumeUnitUKOZ() ? convertCLtoUKOZ(p)
                                             : convertCLtoUSOZ(p));

      myDisplay.setScaleData(i, w, v, p, t, myScale.isConnected(idx));
      float keg_vol = myConfig.getKegVolume(idx) *
                      100.0f;  // Convert from liters to centiliters
      myDisplay.setKegInfo(idx, keg_vol);
      myDisplay.setBeerInfo(idx, myConfig.getBeerName(idx),
                            myConfig.getBeerABV(idx), myConfig.getBeerEBC(idx),
                            myConfig.getBeerIBU(idx));
    }
  }

  // Handle peridoic updadates like pushing data and reading temperature sensors
  if (loopTimer.hasExpired()) {
    loopTimer.reset();

    // Read temperature at interval.
    if (!(loopTimer.getLoopCounter() % 15)) {
      Log.notice(F("LOOP: Reading temperature sensors." CR));
      myTemp.read();
    }
  }
}

void checkCoreDump() {
#if defined(CONFIG_IDF_TARGET_ESP32S2) || defined(CONFIG_IDF_TARGET_ESP32S3)
  esp_core_dump_summary_t *summary = static_cast<esp_core_dump_summary_t *>(
      malloc(sizeof(esp_core_dump_summary_t)));

  if (summary) {
    memset(summary, 0, sizeof(esp_core_dump_summary_t));

    if (esp_core_dump_get_summary(summary) == ESP_OK) {
      Log.notice(F("Exception cause %d." CR), summary->ex_info.exc_cause);
      Log.notice(F("PC 0x%x." CR), summary->exc_pc);

      int depth = (summary->exc_bt_info.depth > 16) ? 16 : summary->exc_bt_info.depth;
      for (int i = 0; i < depth; i++) {
        Log.notice(F("PC(%d) 0x%x." CR), i, summary->exc_bt_info.bt[i]);
      }
    }

    free(summary);
  }
#endif
}

LoopTimer myInfluxTimer(1000);

void dumpDataToInfluxDB() {
  // Send raw measurement data to InfluxDB periodically (every 1 second)
  if (myInfluxTimer.hasExpired() && myConfig.hasTargetInfluxDb2()) {
    myInfluxTimer.reset();

    char buf[200];
    float v;
    String s;
    s.reserve(512);

    snprintf(&buf[0], sizeof(buf), "scale,host=%s,device=%s ",
             myConfig.getMDNS(), myConfig.getID());
    s = &buf[0];

    // Temperature data
    for (int i = 0; i < myTemp.getSensorCount(); i++) {
      v = myTemp.getLastTempC(i);
      if (!isnan(v)) {
        snprintf(&buf[0], sizeof(buf), "tempC%i=%f,", i + 1, v);
        s = s + &buf[0];
      }
    }

    // Scale filter data - all computed values
    for (int i = 0; i < MAX_SCALES; i++) {
      ScaleReadingResult res = myScale.getLastResult(static_cast<UnitIndex>(i));

      if (!isnan(res.raw)) {
        snprintf(&buf[0], sizeof(buf), "raw%i=%f,", i + 1, res.raw);
        s = s + &buf[0];
      }
      if (!isnan(res.moving_average)) {
        snprintf(&buf[0], sizeof(buf), "ma%i=%f,", i + 1, res.moving_average);
        s = s + &buf[0];
      }
      if (!isnan(res.ema)) {
        snprintf(&buf[0], sizeof(buf), "ema%i=%f,", i + 1, res.ema);
        s = s + &buf[0];
      }
      if (!isnan(res.weighted_ma)) {
        snprintf(&buf[0], sizeof(buf), "wma%i=%f,", i + 1, res.weighted_ma);
        s = s + &buf[0];
      }
      if (!isnan(res.median)) {
        snprintf(&buf[0], sizeof(buf), "median%i=%f,", i + 1, res.median);
        s = s + &buf[0];
      }
      if (!isnan(res.zscore)) {
        snprintf(&buf[0], sizeof(buf), "zscore%i=%f,", i + 1, res.zscore);
        s = s + &buf[0];
      }
      if (!isnan(res.hampel)) {
        snprintf(&buf[0], sizeof(buf), "hampel%i=%f,", i + 1, res.hampel);
        s = s + &buf[0];
      }
      if (!isnan(res.complementary)) {
        snprintf(&buf[0], sizeof(buf), "comp%i=%f,", i + 1, res.complementary);
        s = s + &buf[0];
      }
      if (!isnan(res.alphabeta)) {
        snprintf(&buf[0], sizeof(buf), "ab%i=%f,", i + 1, res.alphabeta);
        s = s + &buf[0];
      }
      if (!isnan(res.butterworth)) {
        snprintf(&buf[0], sizeof(buf), "butter%i=%f,", i + 1, res.butterworth);
        s = s + &buf[0];
      }
      if (!isnan(res.chebyshev)) {
        snprintf(&buf[0], sizeof(buf), "cheby%i=%f,", i + 1, res.chebyshev);
        s = s + &buf[0];
      }
      if (!isnan(res.kalman)) {
        snprintf(&buf[0], sizeof(buf), "kalman%i=%f,", i + 1, res.kalman);
        s = s + &buf[0];
      }

      // Change detection state data
      float stableWeight = myChangeDetection.getStableWeight((UnitIndex)i);
      float pourVolume = myChangeDetection.getPouringVolume((UnitIndex)i);
      float stableVolume = myChangeDetection.getStableVolume((UnitIndex)i);
      float lastPourVolume = myChangeDetection.getLastPourVolume((UnitIndex)i);
      ChangeDetectionState state = myChangeDetection.getState((UnitIndex)i);
      float confidence = myChangeDetection.getConfidence((UnitIndex)i);
      uint8_t signalQuality = myChangeDetection.getSignalQuality((UnitIndex)i);
      float avgSlope = myChangeDetection.getAverageSlope((UnitIndex)i);

      snprintf(&buf[0], sizeof(buf), "state%i=\"%s\",", i + 1,
               myChangeDetection.getStateString((UnitIndex)i));
      s = s + &buf[0];
      if (!isnan(stableWeight)) {
        snprintf(&buf[0], sizeof(buf), "stable_wgt%i=%f,", i + 1, stableWeight);
        s = s + &buf[0];
      }
      if (!isnan(stableVolume)) {
        snprintf(&buf[0], sizeof(buf), "stable_vol%i=%f,", i + 1, stableVolume);
        s = s + &buf[0];
      }
      // Only export current pouring volume while actively pouring
      if (state == ChangeDetectionState::Pouring && !isnan(pourVolume)) {
        snprintf(&buf[0], sizeof(buf), "pour%i=%f,", i + 1, pourVolume);
        s = s + &buf[0];
      }
      // Always export last completed pour volume
      if (lastPourVolume > 0.0f) {
        snprintf(&buf[0], sizeof(buf), "last_pour_vol%i=%f,", i + 1,
                 lastPourVolume);
        s = s + &buf[0];
      }
      snprintf(&buf[0], sizeof(buf), "signal_quality%i=%d,", i + 1,
               signalQuality);
      s = s + &buf[0];
      if (!isnan(avgSlope)) {
        snprintf(&buf[0], sizeof(buf), "avg_slope%i=%f,", i + 1, avgSlope);
        s = s + &buf[0];
      }
      snprintf(&buf[0], sizeof(buf), "conf%i=%f,", i + 1, confidence);
      s = s + &buf[0];
    }

    // Remove trailing comma if present
    if (s.endsWith(",")) {
      s = s.substring(0, s.length() - 1);
    }

    // Serial.printf(F("InfluxDB2 Data: %s" CR), s.c_str());

    myPush.sendInfluxDb2(
        s, myConfig.getTargetInfluxDB2(), myConfig.getOrgInfluxDB2(),
        myConfig.getBucketInfluxDB2(), myConfig.getTokenInfluxDB2());
  }
}

// EOF

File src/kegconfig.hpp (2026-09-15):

/*
 * KegMon
 * Copyright (c) 2022-2026 Magnus
 *
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
 * Alternatively, this software may be used under the terms of a
 * commercial license. See LICENSE_COMMERCIAL for details.
 *
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
 */
#ifndef SRC_KEGCONFIG_HPP_
#define SRC_KEGCONFIG_HPP_

#include <baseconfig.hpp>
#include <main.hpp>

constexpr auto PARAM_BREWLOGGER_URL = "brewlogger_url";
constexpr auto PARAM_BREWFATHER_USERKEY = "brewfather_userkey";
constexpr auto PARAM_BREWFATHER_APIKEY = "brewfather_apikey";
constexpr auto PARAM_BARHELPER_APIKEY = "barhelper_apikey";
constexpr auto PARAM_DISPLAY_LAYOUT = "display_layout";
// UNUSED: Currently not persisted in config
// constexpr auto PARAM_TEMP_SENSOR = "temp_sensor";
constexpr auto PARAM_WEIGHT_UNIT = "weight_unit";
constexpr auto PARAM_VOLUME_UNIT = "volume_unit";

// JSON array field names for per-scale configuration
constexpr auto PARAM_BREWSPY_TOKENS = "brewspy_tokens";
constexpr auto PARAM_BARHELPER_MONITORS = "barhelper_monitors";
constexpr auto PARAM_SCALES = "scales";
constexpr auto PARAM_BEERS = "beers";

// Nested object keys (used within the above arrays)
constexpr auto PARAM_BREWSPY_TOKEN = "brewspy_token";
constexpr auto PARAM_BARHELPER_MONITOR = "barhelper_monitor";
constexpr auto PARAM_SCALE_FACTOR = "scale_factor";
constexpr auto PARAM_SCALE_OFFSET = "scale_offset";

// Scale calibration constants
constexpr float FACTOR_UNCALIBRATED =
    0.0f;  // Sentinel value: scale needs calibration

constexpr auto PARAM_KEG_WEIGHT = "keg_weight";
constexpr auto PARAM_KEG_VOLUME = "keg_volume";
constexpr auto PARAM_GLASS_VOLUME = "glass_volume";
constexpr auto PARAM_TEMP_SENSOR_ID = "temp_sensor_id";
constexpr auto PARAM_BEER_NAME = "beer_name";
constexpr auto PARAM_BEER_ID = "beer_id";
constexpr auto PARAM_BEER_ABV = "beer_abv";
constexpr auto PARAM_BEER_FG = "beer_fg";
constexpr auto PARAM_BEER_EBC = "beer_ebc";
constexpr auto PARAM_BEER_IBU = "beer_ibu";

struct BeerInfo {
  String _name = "";
  float _abv = 0.0;
  int _ebc = 0;
  int _ibu = 0;
  float _fg = 1;
  String _id = "";
};

struct KegInfo {
  float scaleFactor =
      FACTOR_UNCALIBRATED;  // Must call findFactor() to calibrate
  int32_t scaleOffset = 0;
  float kegWeight = 4.0f;     // Weight in kg
  float kegVolume = 19.0f;    // Volume in liters
  float glassVolume = 0.40f;  // Volume in liters
  String tempSensorId = "";   // OneWire sensor ID for this keg
};

constexpr auto WEIGHT_KG = "kg";
constexpr auto WEIGHT_LBS = "lbs";

constexpr auto VOLUME_CL = "cl";
constexpr auto VOLUME_US = "us-oz";
constexpr auto VOLUME_UK = "uk-oz";

enum DisplayLayoutType { Default = 0 };
enum TempSensorType { SensorDS18B20 = 0 };

class KegConfig : public BaseConfig {
 private:
  String _weightUnit = WEIGHT_KG;
  String _volumeUnit = VOLUME_CL;

  String _brewfatherUserKey = "";
  String _brewfatherApiKey = "";

  String _brewspyToken[MAX_SCALES] = {"", "", "", ""};

  String _barhelperApiKey = "";
  String _barhelperMonitor[MAX_SCALES] = {"Kegmon TAP 1", "Kegmon TAP 2",
                                          "Kegmon TAP 3", "Kegmon TAP 4"};

  String _brewLoggerUrl = "";

  DisplayLayoutType _displayLayout = DisplayLayoutType::Default;
  TempSensorType _tempSensor = TempSensorType::SensorDS18B20;

  KegInfo _kegs[MAX_SCALES];
  BeerInfo _beer[MAX_SCALES];

  int _scaleReadCount = 7;  // Default in HX711 library, should be odd number
  int _scaleReadCountCalibration = 29;

  // Change detection parameters
  int _stabilityDetectionFilterIndex = 12;  // FILTER_KALMAN
  int _pourDetectionFilterIndex = 3;        // FILTER_WEIGHTED_MA (better balance for slow pours)
  uint32_t _levelStabilizationDurationSeconds =
      6;                                     // Increased from 3 to 6 seconds for filter convergence
  uint32_t _pourDurationSeconds = 60;         // Increased from 2 to 60 seconds (prevents early locking on slow flow or noise)
  uint32_t _kegAbsenceDurationSeconds = 30;  // Reduced from 60
  uint32_t _kegReplacementDurationSeconds = 30;  // Reduced from 60
  float _weightAbsentThreshold = 0.1f;           // kg
  float _levelIncreaseThreshold = 0.4f;  // kg (keg replacement, ignore drift)
  float _levelDecreaseThreshold = 0.1f;  // kg (pour detection, 100-150g pours)
  float _pourSlopeThreshold =
      -0.001f;  // kg/sec minimum downward slope (for slow pours) - lowered from -0.002 to catch gradual weight loss
  float _minPourSlope = -0.15f;  // kg/sec maximum flow rate (fastest realistic pour)
  float _maxPourSlope = -0.008f;  // kg/sec minimum flow rate (slowest realistic pour)

 public:
  KegConfig(String baseMDNS, String fileName);

  void createJson(JsonObject& doc) const;
  void parseJson(JsonObject& doc);
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

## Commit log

2026-01-26 Moving code to new repository
    [part32_16mb_coredump.csv]
2026-02-03 Update docs for build
    [scale2_base.stl, scale2_base_cover.stl]
2026-02-05 Fixed uncalibrated state, added options for tft display
    [main.cpp, main.hpp, scale.cpp]
2026-02-06 Update pcb
2026-04-19 Validated tft pin settings with new pcb
2026-09-13 Change pin due to conflict with rgb led
2026-09-13 Fixed flash update, had to move CLK for scale 3 to pin 10
    [main.cpp, main.hpp, scale.cpp]
2026-09-13 Fixed speed detection bug
    [scale.cpp]

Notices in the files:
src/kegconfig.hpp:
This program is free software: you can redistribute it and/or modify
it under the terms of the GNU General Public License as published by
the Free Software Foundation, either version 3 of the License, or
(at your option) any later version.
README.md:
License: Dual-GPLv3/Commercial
